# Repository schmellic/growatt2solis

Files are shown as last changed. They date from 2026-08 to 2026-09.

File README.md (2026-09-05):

# Growatt GBLI 6532 → Solis S6-EH1P8K-L-PLUS CAN translator

An ESP32 gateway that sits between a Growatt GBLI 6532 battery and a Solis
S6-EH1P8K-L-PLUS hybrid inverter, decoding Growatt's low-voltage BMS CAN
protocol and re-emitting it as the Pylontech LV CAN protocol the Solis
understands.

> **Status: working, confirmed live (2026-08-31).** This has now run fully
> live - `SNIFF_ONLY` off, a real GBLI6532 talking through a real T-2Can to a
> real Solis S6-EH1P8K-L-PLUS - through a genuine charge cycle and a genuine
> discharge cycle, both with correct current sign, correct SOC, and the
> Solis's own display confirming the datasheet-derived 208.4 A ceiling
> exactly. The four things that used to be inferred rather than confirmed —
> whether the GBLI 6532 emits the `0x311`-series protocol at all, the
> `0x313` voltage scaling, the real `0x301` keepalive payload, and what the
> PCS WAKE pins do — are all settled from real captures, see
> [`captures/`](captures/) and the "Open questions" section of
> [`CLAUDE.md`](CLAUDE.md) for the full evidence trail, including one new
> finding from this live run: the battery protectively disables itself
> (independent of this gateway) if it loses CAN comms, and recovers cleanly.
>
> **Licence: GPLv3.** See [`LICENSE`](LICENSE). You're free to use, modify and
> redistribute this, including commercially — but if you distribute the
> firmware (or a device running it), you must make the corresponding source
> of what you shipped, including your own changes, available under GPLv3 too.

> **Safety.** This sits in the control path of a 48 V, ~100 A battery. A bug here
> can mean the inverter charges past the BMS's limits. The battery's own
> protection MOSFETs remain the last line of defence, but do not treat them as
> the only one. Configure conservative charge voltage / SOC limits in the Solis
> menu as well, commission with the DC breaker in reach, and watch the first
> full charge and discharge cycle before leaving it unattended.

---

## Why a translator is needed

The two devices genuinely do not speak the same language:

| | Growatt GBLI 6532 | Solis S6-EH1P8K-L-PLUS |
|---|---|---|
| Protocol | Growatt LV BMS CAN | Pylontech LV CAN (`PYLON CANBUS V1.2`) |
| Bit rate | 500 kbit/s | 500 kbit/s |
| ID format | 11-bit standard | 11-bit standard |
| **Byte order** | **big-endian** | **little-endian** |
| Frames out | `0x311 0x312 0x313 0x314 0x315–0x318 0x319 0x320 0x321` | `0x351 0x355 0x356 0x359 0x35C 0x35E` |
| Frames in | `0x301` (keepalive from inverter) | `0x305` (keepalive from inverter) |

Bit rate and ID format match, so no rate conversion is needed — but every field
has to be re-laid-out, byte-swapped, and the fault bits re-mapped.

There is **no DIP switch on the GBLI 6532 that makes it emit Pylontech**. Growatt
does protocol selection on the *inverter*, not the battery, so with a Solis on
the other end there is nothing to select. Hence this gateway.

### Frame mapping

| Growatt | → | Pylontech | Notes |
|---|---|---|---|
| `0x311` CVL / CCL / DCL | → | `0x351` | byte-swapped; both current fields stay **positive magnitudes** |
| `0x313` SOC, SOH | → | `0x355` | promoted to uint16 |
| `0x313` V / I / T | → | `0x356` | voltage normalised to 0.01 V; **current sign is the same on both sides (+ = charging)**, so no flip |
| `0x312` protection + warning | → | `0x359` | bit positions differ — explicitly re-mapped |
| `0x319` enables + force-charge | → | `0x35C` | bit positions differ |
| — | → | `0x35E` | fixed `"PYLON "` |
| `0x301` | ← | — | gateway generates it toward the battery |

---

## Hardware

You need **two independent CAN buses**. Do not join them — that is the whole point.

Full shopping list, with prices and the pitfalls, is in **[`PARTS.md`](PARTS.md)**.
Short version:

| Board | `BOARD` in `config.h` | Notes |
|---|---|---|
| **Autosport Labs ESP32-CAN-X2** (~£45) | `BOARD_ESP32_CAN_X2` *(default)* | ESP32-S3. CAN1 = built-in TWAI, CAN2 = MCP2515 @ 16 MHz — exactly this firmware's architecture, nothing to port. Breakable 120 Ω jumpers. Not isolated. |
| **ESP32 DevKit + SN65HVD230 + MCP2515** (~£20) | `BOARD_ESP32_DEVKIT` — use the `translator-devkit`/`sniffer-devkit` PlatformIO envs, no `config.h` edit needed | Budget. **The common blue MCP2515 module is 5 V and the ESP32 is not 5 V tolerant** — see `PARTS.md` before wiring it. |
| **LilyGo T-2Can** (non-FD, ~£27) | `BOARD_LILYGO_T2CAN` — use the `translator-t2can` env, no `config.h` edit needed | ESP32-S3, same TWAI+MCP2515 architecture as the CAN-X2 (just different pins). **Confirmed isolated** — each channel has its own Mornsun TD501MCAN (power + signal isolation, 2500 VDC). Every pin assignment confirmed against a real board, and this is the board this project has actually run live on for days at a time — see `PARTS.md` for the full confirmation trail. |

Pin assignments for all supported boards live in the `BOARD` block at the top of
`config.h`.

### Termination

120 Ω at each end of each bus, and **only** at the ends. Both of your buses are
two-node: ESP32↔battery, and ESP32↔Solis.

- **Inverter bus:** the Solis terminates internally, so the ESP32 side keeps its
  terminator. End to end you should measure ~60 Ω.
- **Battery bus:** the GBLI terminates its end, so again keep the ESP32's. ~60 Ω.
- **When sniffing a live bus, remove the terminator entirely** — see
  [`SNIFFING.md`](SNIFFING.md). A third resistor on an already-terminated bus can
  break the working link.

Measure with a multimeter before powering anything.

---

## Wiring

### Battery end — GBLI 6532 **PCS** port

The GBLI 6532 has three RJ45 sockets. Use **PCS** (the inverter-facing one). Do
**not** use Link-In / Link-Out — those carry the inter-battery bus on different
pins and would silently not work.

| Pin | Signal |
|---|---|
| 1 | RS485-B |
| 2 | RS485-A |
| 3 | GND-ISO |
| **4** | **CAN_H** ← blue |
| **5** | **CAN_L** ← blue/white |
| 6 | GND-ISO |
| 7 | PCS-WAKE− |
| 8 | PCS-WAKE+ |

### Inverter end — Solis battery COM port

| Pin | Signal |
|---|---|
| **4** | **CAN_H** ← blue |
| **5** | **CAN_L** ← blue/white |

T568B on both ends. Pins 4/5 on both sides means a standard patch cable is
pin-compatible — you're just cutting each one and landing it on the ESP32.

### Two things that catch people out

1. **The WAKE pair (PCS pins 7/8) — not actually needed, don't wire it.**
   Earlier revisions of this doc suspected the GBLI needed WAKE driven to
   come out of sleep. Since ruled out three independent ways (validated
   optocoupler monitoring, direct multimeter reading, and a CAN-only cable
   that sustained *and* revived a real pack with WAKE physically absent —
   see `CLAUDE.md`'s open questions) — plain CANH/CANL is all you need. If
   you see nothing on the battery bus, check wiring/termination/TX-RX swap
   first, not WAKE.
2. **The master-select plug.** The GBLI uses plugs on the Link-In/Link-Out ports
   to elect the master pack. A standalone battery still needs the correct plug
   fitted or it may never enumerate.

### Termination

120 Ω at each end of each bus. The Solis has termination built in, so fit one
120 Ω resistor across CAN_H/CAN_L at the ESP32's inverter-side transceiver.
End-to-end you should measure ~60 Ω. Same on the battery side.

---

## Build

PlatformIO:

```bash
pio run -t upload           # ESP32-CAN-X2 (default)
pio device monitor
```

On the budget ESP32 DevKit board, use `-e translator-devkit` (or
`-e sniffer-devkit`) instead — it targets the classic ESP32 and sets
`BOARD_ESP32_DEVKIT` for you, no `config.h` edit required. On a LilyGo T-2Can,
use `-e translator-t2can` (the plain `sniffer` env already targets it for
phase-1 sniffing — see `PARTS.md`).

Arduino IDE: install **coryjfowler/MCP_CAN_lib**, copy `src/*.cpp` and `src/*.h`
into a sketch folder, rename `main.cpp` to match the folder.

Run the host-side tests any time you change the translation logic — they check
byte-level encoding, the endianness flip, flag re-mapping, clamping and the
stale-link derate path, with no hardware required:

```bash
cd test && g++ -std=c++17 -I../src -o test_translate test_translate.cpp && ./test_translate
```

---

## Commissioning — do these in order

### Step 1 — sniff the existing Growatt link *(do this first)*

If the batteries are still connected to a Growatt inverter, tap that live bus
before changing anything. It settles four things that no datasheet does: whether
the GBLI really speaks this protocol, the `0x313` voltage scaling, the real
`0x301` keepalive payload, and what the WAKE pins do.

Full procedure in **[`SNIFFING.md`](SNIFFING.md)**. It uses a separate
listen-only firmware build that cannot disturb the working system:

```bash
pio run -e sniffer-devkit -t upload && pio device monitor
```

If the Growatt is already gone, the same build works against the battery alone —
you just won't capture `0x301`.

### Step 2 — fold what you learned into `config.h`

- Set `GROWATT_0x313_VOLT_SCALE` to `VS_0V01` or `VS_0V1` instead of `VS_AUTO`.
- If the real `0x301` payload differs from the spec example, update
  `sendGrowattKeepalive()` in `src/main.cpp`.
- If `0x312` reported more than one pack, check `PYLON_PACK_COUNT`.

### Step 3 — dry-run the translator on the battery alone

Build the `translator` env with `SNIFF_ONLY` still `true`, battery bus connected,
inverter bus not. Confirm the summary line is sane:

```
[42s] OK V=52.50V I=+20.0A T=23.4C SOC=62% SOH=100% | CVL=56.8V CCL=60.0A DCL=90.0A | ...
```

SOC should match the Growatt app. Current should be positive while charging.

### Step 4 — configure the Solis

Confirmed against the real Solis manual (2026-08-31). Two menu paths get you
there:

- First-time quick setup: `Inverter Time → Meter Setting → Grid Code →
  Storage mode → Battery Model`
- Later, via the detailed menu: Home page → `SYSTEM SETTING` → `Storage Mode`
  (mode/reserve settings) and → `Battery Setting` (the current/SOC limits
  below)

Battery Model: **`PYLON_LV`**.

(`Lithium Battery LV` is the documented fallback and also works, but `PYLON_LV`
is the profile a Solis has been verified against with this protocol.)

On the `Battery Setting` screen:

| Setting | Manual's range/default | Recommended starting value |
|---|---|---|
| Max charge current | settable | **~20–30 A**, not the pack's theoretical max |
| Max discharge current | settable | **~20–30 A**, same reasoning |
| Over discharge | 5–40%, default 20% | manual default is fine |
| Recovery | over-discharge +1–20% | manual default is fine |
| Force charge | must be < Over discharge < Recovery | leave at default |
| Max charge SOC | default 100% | **95%**, not 100% |

**Why start well below the pack's real capability:** this is the first time
the whole chain - BMS → gateway → Solis → actual power flow - runs live. Low
current keeps any real mistake small and slow to develop while you watch the
first cycle. Raise it in steps once you've seen a clean cycle, rather than
jumping straight to the pack's rating. This project's gateway clamps
everything to a per-pack ceiling of 104.2 A - confirmed against the real
GBLI6532 datasheet (5 kW / 104.2 A max) - multiplied by the live pack count
from `0x312` (`CCL_MAX_PER_PACK_dA`/`DCL_MAX_PER_PACK_dA` in `config.h`), so
a 2-pack system's real ceiling is 208.4 A. That's a real confirmed rating,
not a soft guess, but it's still well above where you'd want to start a
first live test.

**Why 95% not 100% for Max charge SOC:** the Solis appears to partly ignore
the CAN charge-voltage limit and use its own float setting, so **do not rely
on `0x351` CVL as your only over-charge protection** - capping SOC at 95%
gives a real margin independent of anything CAN-based.

### Step 5 — go live

Set `SNIFF_ONLY` to `false`, reflash, connect the inverter bus. Within a few
seconds the Solis should stop reporting `Batt_Comm_FAIL` and show the battery
SOC. `inv0x305=yes` in the serial summary confirms the inverter is talking back.

Watch a full charge and a full discharge before leaving it alone. Check that the
inverter's reported battery power direction matches reality — if charge/discharge
appear inverted, the `0x356` current sign needs flipping (it shouldn't; both
protocols use positive = charging, but it's the one thing worth eyeballing).

---

## Failure behaviour

| Condition | Response |
|---|---|
| No battery frames yet | Nothing transmitted; Solis raises `Batt_Comm_FAIL` and stays disconnected |
| Battery silent > 5 s | Charge and discharge current limits forced to 0, `0x35C` enables cleared, `0x359` system-error set |
| Battery silent > 30 s | Transmission stops entirely; Solis faults and disconnects |
| BMS reports a protection | Re-mapped into `0x359`; Solis surfaces it as `Alarm-BMS` |
| Absurd BMS values | Clamped to the ceilings in `config.h` before forwarding |

The design principle throughout: when in doubt, ask the inverter for **less**,
and fail toward disconnection rather than toward uncontrolled current.

---

## A note on Battery-Emulator

[dalathegreat/Battery-Emulator](https://github.com/dalathegreat/Battery-Emulator)
already contains a mature, field-proven `PYLON-LV-CAN` **inverter** implementation —
the exact output side this project needs. What it lacks is a Growatt **low-voltage**
battery decoder (it supports Growatt ARK **HV** only).

So the better long-term route, once you've confirmed the frame layout on your own
pack, is to contribute a `GROWATT-LV-BATTERY` decoder to that project. You'd
inherit its webserver, MQTT/Home Assistant integration, OTA updates, event log and
its much broader testing — and `translate.h` here is essentially the decoder that
would need porting.

Worth knowing if you do: Battery-Emulator's `PYLON-LV-CAN.cpp` `0x359` over-current
logic appears to have a sign bug (it treats positive current as discharge, which
contradicts its own datalayer convention). This project drives those bits from the
BMS's own protection flags instead, which is more reliable anyway.

---

## Protocol references

- Growatt BMS CAN-Bus protocol, low voltage — [V1.04 PDF](https://www.amosplanet.org/wp-content/uploads/2022/04/Growatt-BMS-CAN-Bus-protocol-low-voltage-V1.04-1.pdf)
- PYLON CANBUS protocol V1.2 — [spec PDF](https://akkudoktor.net/uploads/short-url/oLZIl9bFdMC1doN4OnIvXbazHMl.pdf)
- Solis Modbus register map (registers 33141–33146 mirror the BMS CAN frames, which is how the field scalings were cross-checked) — [PDF](https://akkudoktor.net/uploads/short-url/kbwIjN8pl8idrCP04UstaxtSmlC.pdf)
- GBLI 6532 quick installation guide (PCS/Link pinouts) — [PDF](https://solsol.eu/file/view/1805/growatt_instman_gbli-6532-quick-guide_en.pdf)
- Solis S6-EH1P8K-L-PLUS user manual — [PDF](https://139708663.fs1.hubspotusercontent-eu1.net/hubfs/139708663/Fiches%20techniques/Solis/Solis_Manual_S6-EH1P8K-L-PLUS_EUR_V1,2(20251030).pdf)
- `martc55/Jbd2Solis` — a JBD-BMS→Solis Pylon emulator, verified working against a Solis LV hybrid — [GitHub](https://github.com/martc55/Jbd2Solis)
- `edibg/growattArkCAN` — independent capture of Growatt `0x311`/`0x313` — [GitHub](https://github.com/edibg/growattArkCAN)

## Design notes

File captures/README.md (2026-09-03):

# CAN captures

Raw serial output from `pio run -e sniffer`, committed so the protocol decoding
can be checked against real traffic rather than against a datasheet.

**This is the point of the repo.** Growatt's LV BMS CAN protocol is documented,
but I could find no published capture from a **GBLI 6532** specifically — every
byte layout in `src/translate.h` is inferred from the spec plus a capture of the
sibling ARK pack. A capture here turns inference into fact.

## Capturing

```bash
pio run -e sniffer-devkit -t upload   # plain ESP32 DevKit + SN65HVD230 (phase 1 hardware)
pio device monitor | tee captures/$(date +%F)-gbli6532-sph6000.log
```

Let it run for at least a few minutes, ideally spanning a charge→discharge
transition so the signed current field is exercised in both directions.

**Also worth a separate capture: a cold boot.** Start logging *before*
powering the GBLI/inverter link on, not after — a steady-state capture can't
show the `0x301`/`0x311` handshake or when WAKE+ toggles relative to it,
since both only happen once at power-on. See "Bonus: capture a cold boot" in
`SNIFFING.md` for the detailed procedure. The interesting part is the first
~30 seconds; a longer tail afterwards is free insurance but not where the
handshake data is.

## Naming

```
YYYY-MM-DD-<battery>-<inverter>-<what-was-happening>.log
```

e.g. `2026-08-24-gbli6532-sph6000-idle.log`,
`2026-08-24-gbli6532-sph6000-charging-20A.log`,
`2026-08-24-gbli6532-sph6000-coldboot.log`

## What to note alongside each capture

Add a line to the table below. The cross-checks are what make a capture useful —
a log with no reference readings can't resolve a scaling question.

| Capture | Pack V (app/meter) | SOC (app) | Current (app) | Notes |
|---|---|---|---|---|
| _example_ | 52.5 V | 62 % | +20 A charging | |
| `2026-08-23-gbli6532-sph6000-coldboot.log` | not cross-checked | not cross-checked | not cross-checked | Real cold boot into a full idle → discharge (to −9.8 A) → charge (to +7.9 A) cycle, via manually toggling solar off/on. Resolved most of `CLAUDE.md`'s open questions 1, 2, 3, 5, 6. CAN-reported: 53.20–53.40 V, SOC 99%. |
| `2026-08-23-gbli6532-sph6000-battery-only.log` | not cross-checked | not cross-checked | not cross-checked | Battery powered (via its POWER button) with the inverter left off. Shows the battery transmits `0x311` etc. on its own but stays in a disabled `mode=0` state (`CCL=DCL=0.0A`) with no inverter present. CAN-reported: ~53.1 V, SOC 99-100%. |
| `2026-08-23-gbli6532-sph6000-wake-test.log` | not cross-checked | not cross-checked | not cross-checked | Inverter powered first (alone for a while, `0x301` only), then battery POWER button pressed with the exact moment noted live. Shows `mode=0 → mode=1` (fully enabled) within 2-4 seconds of the battery's first frame. Resolved `CLAUDE.md` open question 4 (WAKE not needed). |
| `2026-08-31-gbli6532-t2can-translator-dryrun.log` | not cross-checked | 96% | +0.0A idle | **First-ever capture from the real translator firmware (`translator-t2can`), not the sniffer** - README's commissioning Step 3, battery bus only, inverter bus unconnected. `chg=0 dis=0` on reconnect → `chg=1 dis=1, CCL=DCL=25.6A` within 4s, matching the wake-test pattern exactly. Clean throughout: SOH=99%, packs=2, no faults, `inv0x305=no` correctly reflecting no inverter connected. |
| `2026-08-31-gbli6532-t2can-solis-live-nodc.log` | not cross-checked | 87% | +0.0A idle | First `SNIFF_ONLY` off run against the real Solis, but with DC power deliberately left disconnected - confirms the entire CAN/data path (real Pylon frames, real Solis interpreting them, `inv0x305=yes`) with zero possibility of real current flow. Solis's own display showed `CCL`/`DCL=208.4A` exactly matching the datasheet-derived ceiling, SOC/voltage matching. Solis itself correctly reported "No Battery" as its overall status with DC disconnected - sensible behavior, distinguishing "valid BMS comms" from "usable connected battery". |
| `2026-08-31-gbli6532-t2can-solis-live-charging.log` | not cross-checked | 86-87% | -47.2A to +4.8A | **First fully live run** - `SNIFF_ONLY` off, real Solis attached, DC connected, README Step 5. Confirmed `CCL=DCL=208.4A` on the Solis's own display exactly matching the datasheet-derived 2-pack ceiling. Also captured a real event: the T-2Can was physically disconnected mid-discharge (to move it to a laptop) - battery responded with a protective `chg=0 dis=0` disable and its ALM light/relays opening (t=116s), recovering cleanly within ~4.5 minutes of reconnection (t=390s) with no repeat. `prot=`/`warn=` stayed `0000` throughout the whole event - whatever triggers this protective response isn't visible in the `0x312` bytes this project currently decodes. See `CLAUDE.md`'s safety posture notes. |
| `2026-08-31-gbli6532-t2can-laptop-power-10min.log` | 53.0-53.2V | 84% | -32.4A to +0.0A | Raw serial capture (`cat /dev/ttyACM0`, not `pio device monitor` - that needs a real TTY and can't run backgrounded/unattended) while diagnosing a reported "disconnects after ~10 minutes" issue. Gateway itself was rock solid throughout - `inv0x305=yes` held, no reboot, keepalive never missed a beat - but the battery's own `0x311` enable bits flipped `chg=1 dis=1` → `chg=0 dis=0` at t=648s (10m48s) and stayed disabled for the rest of the 16+ minute capture, no self-recovery. `prot=`/`warn=` stayed `0000`. First two clean measurements of the exact 594 s enable-to-disable interval (t=58s→652s and t=1090s→1684s, identical to the second). See `CLAUDE.md` open question 8 - unresolved. |
| `2026-08-31-gbli6532-sph6000-t2can-sniffer-594s-test.log` | not cross-checked | not cross-checked | +0.0A to -57.1A | Real SPH6000 reconnected directly to the battery (one shared bus, same RJ45-splitter tap technique as the original `SNIFFING.md` procedure), T-2Can as a passive listen-only tap (`sniffer-t2can` env, new - the plain `sniffer` env is missing the `ARDUINO_USB_CDC_ON_BOOT` flag the T-2Can needs). Ran 14m51s with **zero disables** - `chg_en=1 dis_en=1` the whole time, including through a sustained -56.6A real discharge. The decisive test for open question 8: a real Growatt inverter does not hit the 594s wall this gateway does. Also confirmed the real `0x301` payload is byte-for-byte identical to what this gateway sends. |
| `2026-08-31-gbli6532-t2can-batteryonly-594s-clean.log` | ~53.1V | 72% | +0.0A idle | Battery ↔ T-2Can only - no Solis, no SPH6000, cleanest possible topology, running the newly-instrumented `translator-t2can` (`VERBOSE_STATS` added to `main.cpp`/`config.h`). Confirmed the 594s interval a third time, independently: enable at t=68s (after a manual power cycle triggered by a brief comms gap from reflashing), disable at t=664s = 596s, within the 2s print-resolution margin of the first two measurements. Rules out the Solis or SPH6000 having anything to do with the timer - it's purely between this gateway's replay and the battery. |
| `2026-08-31-gbli6532-t2can-twai-health-594s.log` | ~53.0-53.1V | 70-72% | +0.0A idle | Battery ↔ T-2Can only again, this time with TWAI bus-health stats (`tx_err`/`rx_err`/`tx_failed`/`rx_missed`/`rx_overrun`/`arb_lost`/`bus_err`) also logged. Steady-state health was completely clean throughout (all zero except a one-time startup `rx_missed=111` that never grew) right up to and through another clean disable at t=518s (enable t=10s, so 508s - within the usual margin). Rules out an electrical/bus-health difference as the cause, at least in this clean two-node topology. |
| `2026-09-02-gbli6532-sph6000-devkit-txrx-fixed-test.log` | 51.9-53.1V | ~70% | +0.0A idle | Phase-1 DevKit + SN65HVD230, confirming the fix for a real "BMS Com fault" that turned out to be D(TXD)/R(RXD) wired to the wrong GPIOs (not the ground-loop or termination theories tried first, both real fixes in their own right but not the actual cause). Real `0x301`/`0x311`-series traffic flowing cleanly once corrected, fault cleared on the SPH6000's display. |
| `2026-09-03-gbli6532-sph6000-devkit-can-wake-combined-session.log` | 51.9-53.1V | 21-72% | +0.0A to -57A | The big one: 30 min clean baseline with a WAKE-pin optocoupler monitor running for the first time (zero edges logged the entire time), then a deliberate SPH6000 disconnect/reconnect cycle - disable at t=2388.243s, re-enable at t≈2501.27s, again zero WAKE edges through the whole transition. Also the source of the strongest lead yet: a full byte-diff across every ID (not just the decoded ones) around both transitions found `0x323` byte 4 flipping `00→04` at t=2389.027s (0.8s after disable) and back `04→00` at t=2499.197s (2s before re-enable) - the first CAN-visible signal found all project that actually correlates with this state. See `CLAUDE.md` open question 8. |
| `2026-09-03-gbli6532-devkit-t2can-swap-test.log` | 51.9-53.1V | 21% | +0.0A idle | Independent second data point for the `0x323` byte 4 finding, different session/topology (battery + DevKit sniffer + T-2Can, mid swap-without-power-cycle test, contaminated by a severe bus-error problem from removing the SPH6000's terminator - see the txresult-check log below). Byte 4 flipped to `04` at t=502.053s, disable followed at t=507.5s (5.4s later - the opposite order from the combined-session log, so the exact lead/lag relationship isn't consistent yet). |
| `2026-09-03-gbli6532-t2can-own-perspective-check.log` | 51.9V | 21% | +0.0A idle | T-2Can's own serial output during the swap test, checked because the battery never re-enabled after the swap. Confirmed the T-2Can was receiving real `BAT RX` frames from the battery fine (bus connection genuinely good), but its own `chg=0 dis=0` never flipped - led to checking the TWAI health stats next. |
| `2026-09-03-gbli6532-t2can-txresult-check.log` | - | - | - | Added a debug print logging the actual return value of `twai_transmit()` for the keepalive (previously discarded entirely) - confirmed `ESP_OK` every single call, so the keepalive genuinely is being sent. But the TWAI health stats in the same capture showed `bus_err=852260` and a slowly-recovering `tx_err`, pointing at a severe electrical problem (most likely the bus left under-terminated after removing the SPH6000, with nothing confirmed replacing its terminator) rather than a software/logic issue. Termination re-check was still pending when this session paused. |
| `2026-09-03-wake-positive-control-test.log` | - | - | - | First attempt at a positive-control test for the WAKE-pin optocoupler monitor (deliberately applying a known 3.3V test pulse to confirm the detector circuit actually works before trusting a "no signal" result). Invalid - the test source shared a ground/rail with the ESP32 itself, defeating the point of testing the isolated path. Superseded by `-final` below. |
| `2026-09-03-wake-positive-control-final.log` | ~53.0V | ~72% | not cross-checked | The valid positive-control test, after root-causing the circuit's insensitivity to a too-strong combined pull-up (module's own 10kΩ + ESP32's internal ~45kΩ) and an under-driven LED (fixed with an external 1MΩ-only pull-up plus a 5V/~19mA LED drive). Logged real edges (#0-#3) for the first time, proving the detector genuinely works - a prerequisite for trusting the zero-edges result from the real-system tests. |
| `2026-09-03-gbli6532-sph6000-devkit-wake-corrected-30min.log` | 51.9-53.1V | not cross-checked | +0.0A idle | First real-system WAKE monitor run with the corrected (validated) circuit - 36+ minutes against the real SPH6000, zero WAKE edges logged. Combined with the positive-control validation above, this is trustworthy evidence (not just an unvalidated null result) that WAKE carries no signal in normal operation. |
| `2026-09-03-gbli6532-sph6000-can-only-nowake-test.log` | not cross-checked | not cross-checked | not cross-checked | Real SPH6000 connected via a purpose-built CAN-only cable (RJ45 pins 4/5 only, WAKE genuinely physically absent, not just unmonitored). Ran 41+ minutes sustained with no issues - independent confirmation that WAKE isn't required for normal operation, on top of the pin-monitoring result above. |
| `2026-09-03-gbli6532-t2can-revival-test.log` | 53.9-54.0V | 100% | +0.0A idle | First test of whether this gateway itself (not just the real SPH6000) can revive an already-locked battery via reconnection alone. It could not - `chg_en=0 dis_en=0` stayed locked well past the point where the SPH6000's equivalent reconnection had already worked. Later review found this specific log shows **zero individually-timestamped `0x301` frames** anywhere in its visible ~975-1035s window (only a frozen stats-table row with a placeholder payload), which cast doubt on the result until the keepalive-tx-verify test below confirmed transmission really was reliable in equivalent conditions. Turned out to be superseded anyway: the real cause was the wrong `0x301` payload (see `CLAUDE.md` open question 8's resolution), not a transmission problem. |
| `2026-09-03-gbli6532-t2can-clean-burst-test.log` | 53.9-54.0V | 100% | +0.0A to +0.3A | The key clean single-cycle reference session (pre-payload-fix): gateway-only, perfectly metronomic `0x311` throughout with no burst, natural disable at t=565.357s (~594s pattern, still on the buggy payload), `0x323` byte 4 flip at t=564.246s (third independent confirmation of that correlation, 1.1s *before* the disable this time). Then the real SPH6000 was swapped in and revived the battery at t=760.195s - later re-measured in the revival-repeat log as near-instant (~1.5s) once the inverter was actually live, with most of that apparent gap being the inverter's own self-test/boot time, not battery-side delay. Also where the `0x311` burst-timing phenomenon (bursty cadence correlating with unconfirmed/fresh connections, not with the 594s wall) was characterized. |
| `2026-09-03-gbli6532-sph6000-revival-repeat.log` | 53.6-54.2V | 100% | +0.0A to +0.3A | Careful repeat of the SPH6000 revival test for extra confidence. Battery confirmed still locked at t=21s/44.5s, SPH6000 reconnected at t≈44.5s, `chg_en`/`dis_en` flipped back to 1 at t=46.033s - about 1.5s later, sustained and clean through t=59s+. Corrected the earlier "194.8s locked" framing from the clean-burst-test log: that was mostly the SPH6000's own reconnection/self-test process, not the battery being slow - Paul confirmed directly that the relays click immediately every time the SPH6000 goes back in. |
| `2026-09-03-gbli6532-t2can-keepalive-tx-verify.log` | 53.9-54.0V | 100% | +0.0A to +0.3A | Instrumented rerun (`VERBOSE_KEEPALIVE_TX`, still on the buggy payload) to check whether `twai_transmit()` itself was ever silently failing. Found it returns `ESP_ERR_TIMEOUT` when nothing is on the bus to ACK (expected CAN behavior, 30/30 failures confined to the pre-connection window) but was 100% reliable (`ESP_OK`, `bus_err` frozen, `tx_err` recovering to 0) for the entire 598s enable-to-disable cycle and beyond - ruling out transmit reliability as the cause of the natural disable. Also repeated the gateway self-revival attempt on this verified-good-transmit build: still failed to revive, `0x323` byte 4 read `0x04`, closing out the earlier doubt about the `-revival-test.log` result - the revival failure was real, just not (as it turned out) for a transmission reason. |
| `2026-09-03-gbli6532-t2can-post-revival-check.log` | not cross-checked | not cross-checked | not cross-checked | Brief live-status check partway through the keepalive-tx-verify session, low information value on its own. |
| `2026-09-03-gbli6532-t2can-correctpayload-test.log` | 53.4-53.9V | 100% | +0.0A to +0.3A | **The fix confirmation.** After finding `sendGrowattKeepalive()` had been sending the protocol document's example placeholder payload (`11 22 33 44 55 66 77 88`) instead of the real captured value since the project's first commit, corrected it to the real payload and reflashed. Battery enabled normally at t=51s and **stayed enabled 2793+ seconds (46+ minutes) with zero disables**, nearly 5x past the old ~594s wall - resolving `CLAUDE.md` open question 8. Live-monitored by Paul throughout. |

## Open questions these should answer

1. Does the GBLI 6532 emit `0x311`/`0x312`/`0x313` at all, or something else?
2. Is `0x313` bytes 0–1 scaled **0.01 V** (Growatt spec) or **0.1 V**
   (`growattArkCAN` observation)?
3. What is the real `0x301` payload from a Growatt inverter, and does any byte
   change over time — especially during the power-on handshake, not just in
   steady state?
4. What are the actual transmit periods for each ID? Only `0x301`'s ~1 s cadence
   is documented.
5. What voltage/pattern does the inverter apply to the WAKE pins (PCS 7/8),
   and when relative to the `0x301`/`0x311` handshake? See `CLAUDE.md`'s open
   questions for why this one might mean new hardware, not just new config.
6. Does `0x311` byte 6 or byte 7 carry the charge/discharge-enable bits? This
   project's own tests concluded byte 7; a secondhand report elsewhere claims
   byte 6. See `CLAUDE.md`.

See `SNIFFING.md` for the wiring and the safety notes — in particular, remove the
120 Ω terminator from your transceiver module before tapping a live bus.

## Note

Captures are battery telemetry — voltages, currents, SOC. Nothing personally
identifying, so they're safe to publish. Do check before committing anything
you've hand-annotated, though.

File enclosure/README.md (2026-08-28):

# Enclosure

`BMS_Translator_Case.stl` / `BMS_Translator_Lid.stl` — the 3D-printable
enclosure for the LilyGo T-2Can translator board (Phase 2 hardware),
designed against the real board and the real RJ45-to-RJ45 panel-mount
couplers rather than placeholder dimensions.

Designed externally (Fusion 360), not from a parametric source tracked in
this repo — these STLs are the source of truth. There's no `.scad`/`.f3d`
file here to regenerate them from; if the design needs to change, it's
edited at the source and the STLs re-exported and dropped in here.

## Parts referenced

- LilyGo T-2Can (non-FD) — see `PARTS.md`. Confirmed: CAN connections are
  screw terminals, not onboard RJ45 jacks - each RJ45 coupler wires directly
  to its screw terminal block.
- RJ45-to-RJ45 panel-mount coupler, 2-pack (one per CAN bus) —
  [PENGLIN RJ45 8P8C horizontal female adapter](https://www.amazon.co.uk/dp/B0GGBC8JXG)

## History

An earlier parametric OpenSCAD design (`t2can_enclosure.scad`) lived here
first, built from placeholder/unverified board and coupler dimensions before
either part was in hand. Superseded once the real hardware arrived and a
proper design could be done against it - removed rather than kept as a
stale fallback.

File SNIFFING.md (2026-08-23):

# Sniffing your live GBLI 6532 ↔ Growatt SPH6000 link

Having the batteries currently on a Growatt inverter is the single most useful
thing about your situation. A working Growatt pair on the bench answers four
questions that no datasheet does:

1. **Does the GBLI actually speak the documented `0x311`-series protocol?**
   The Growatt LV BMS CAN spec is public, but I could not find a single published
   capture taken from a **GBLI 6532** specifically. Everything in this firmware's
   battery-side decoding is inferred from the spec plus a capture of the ARK
   pack. Your bus settles it.

2. **Is `0x313` scaled 0.01 V or 0.1 V?** Growatt's own document says 0.01 V; the
   `growattArkCAN` project observed 0.1 V. Both fit in an int16 for a 48 V pack.

3. **What is in `0x301`?** This is the keepalive the inverter sends *to* the
   battery, once per second. Growatt's spec gives an example payload
   (`11 22 33 44 55 66 77 88`) and no semantics at all. Your SPH6000 is sending
   the real thing right now. If the GBLI needs it to stay awake and talking, this
   capture is the difference between the gateway working and the battery going
   silent after 30 seconds.

4. **What do the WAKE pins actually do?** You can measure pins 7/8 on a working
   link instead of guessing.

---

## Before you start

The bus you're tapping is keeping a real battery and a real inverter talking. Two
rules:

- **Listen-only.** The sniffer firmware puts the CAN controller in
  `TWAI_MODE_LISTEN_ONLY`. It never sends an ACK bit, never transmits, never
  sends an error frame. Electrically it's a passive stub. Use the `sniffer`
  build, not `SNIFF_ONLY` in the translator build — the latter still has an
  active controller that ACKs.
- **No third terminator.** Remove the 120 Ω resistor from your SN65HVD230 module
  (see `PARTS.md`). Still the recommended practice even though a real capture
  session ran fine with it left in (40 Ω instead of ~60 Ω) - see the
  real-world update in `PARTS.md` for why that's not a reason to skip it.

---

## Wiring the tap

The GBLI's **PCS** port is the one that goes to the SPH6000 — not Link-In or
Link-Out, which carry a different bus on different pins.

```
  GBLI PCS ──────── existing cable ──────── SPH6000 battery port
                         │
                    RJ45 splitter        ← parallel-wired, all 8 pins
                         │
                    ≤ 30 cm stub
                         │
              RJ45 breakout
                    pin 4 (blue)      → SN65HVD230  CAN_H
                    pin 5 (blue/white)→ SN65HVD230  CAN_L
                                        SN65HVD230  3V3 → ESP32 3V3
                                        SN65HVD230  GND → ESP32 GND
                                        SN65HVD230  CTX → ESP32 GPIO 5
                                        SN65HVD230  CRX → ESP32 GPIO 4
```

Don't connect pins 7/8 (WAKE) — you're not the inverter and shouldn't act like
one. Don't connect the RS485 pair either.

Before plugging in: multimeter across the breakout's pins 4 and 5 with the stub
connected but the ESP32 unpowered. You should read the bus's normal ~60 Ω. If you
read ~40 Ω, you've left a terminator on your module.

---

## Running it

```bash
pio run -e sniffer-devkit -t upload   # plain ESP32 DevKit + SN65HVD230 (phase 1 hardware)
pio device monitor
```

(`sniffer` without `-devkit` targets the ESP32-S3 CAN-X2 board instead — use
`-devkit` for the phase 1 sniffer parts in `PARTS.md`.)

Commands (type the letter, then Enter):

| Key | Does |
|---|---|
| `r` | toggle raw frame logging |
| `d` | toggle decoded Growatt lines |
| `s` | print the statistics table now |
| `c` | clear statistics |

A statistics table prints automatically every 15 s.

---

## What you're looking for

### Expected — the good outcome

```
  ID     count   period(ms)  DLC  last payload             changing
  ----------------------------------------------------------------------
  0x301     120    1000 (998-1002)  8   11 22 33 44 55 66 77 88   ........
  0x311     240     500 (498-503)   8   02 38 02 58 03 84 00 62   ....*..*
  0x312     120    1000 (997-1004)  8   00 00 00 00 01 47 57 10   ........
  0x313     240     500 (498-502)   8   14 82 00 C8 00 EA 3E 64   ***** *.
  0x314     120    1000 (996-1003)  8   1A F8 1C 20 00 0C 00 2B   *.*...**
  0x319     120    1000 (999-1001)  8   60 0D 0A 0D 04 03 08 00   .****...
```

The `changing` column marks bytes that have ever changed value — a quick way to
see which fields are live telemetry and which are constants.

### The three things to write down

**1. The `0x313` voltage scaling.** The decode line prints both interpretations:

```
        0x313  Vraw=5250  -> 52.50V if 0.01V  /  525.0V if 0.1V  |  I=+20.0A ...
```

Compare against the pack voltage in the Growatt ShinePhone app. One of the two
will obviously be right. Then set `GROWATT_0x313_VOLT_SCALE` in `config.h` to
`VS_0V01` or `VS_0V1` rather than leaving it on `VS_AUTO`.

**2. The real `0x301` payload.** The sniffer flags this one specially. If your
SPH6000 sends something other than `11 22 33 44 55 66 77 88`, copy the actual
bytes into `sendGrowattKeepalive()` in `src/main.cpp`. Watch it for a minute —
if any byte changes over time (a counter? a checksum? a command?), that matters,
and it's worth capturing a longer log. A forum user trying the same GBLI6532
pairing with a non-Growatt inverter found that replaying a single static
`0x301` payload (`0B 16 21 2C 37 42 4D 58`, ~10 Hz) was **not** enough on its
own to get the BMS to report charge/discharge-enable — so don't stop at one
captured frame; capture several continuous seconds and watch for it changing.

**2b. Which byte of `0x311` actually carries charge/discharge-enable.** This
project's `translate.h` currently reads them from byte 7 (the low byte of the
big-endian pair) — found via this project's own host tests, correcting an
earlier assumption of byte 6. That same forum thread independently claims
byte 6 (bits 4/5/6 = wake/discharge/charge). Check both bytes in your capture
against what the pack is actually doing (charging vs idle vs discharging) to
settle this for real, rather than trusting either secondhand source.

**3. Anything unexpected.** Frames at IDs this firmware doesn't handle, unusual
periods, or `0x312` reporting a pack count other than 1. Save the whole serial
log — `pio device monitor` can tee to a file:

```bash
pio device monitor | tee growatt-capture-$(date +%F).log
```

### If you see nothing at all

In order of likelihood:

1. CAN_H and CAN_L swapped — try the other way round, you can't damage anything.
2. You tapped Link-In/Link-Out instead of PCS.
3. Termination — you left the resistor on your module, or the splitter has a long
   tail.
4. Wiring standard — check your patch lead is T568B and that pin 4 really is the
   solid blue conductor.

If you see nothing and the battery↔inverter link has *also* stopped working,
unplug immediately: that's the third-terminator failure mode.

### If you see completely different CAN IDs

Then the GBLI 6532 isn't speaking the protocol this firmware assumes, and the
whole battery-side decode needs revisiting. Save the log — that's a solvable
problem, just a different one, and the raw capture is everything needed to solve
it.

---

## Bonus: capture a cold boot

A steady-state capture can't answer two of the open questions: the `0x301`/
`0x311` handshake sequence (open question 3 in `CLAUDE.md`), and whether
WAKE+ toggles at a particular point in that sequence (open question 4). Only
a capture that starts *before* power-on can show that.

- **Start logging before power-on, not after.** Flash and start
  `pio device monitor | tee ...` while the GBLI/inverter link is still cold,
  so `t=0` in the log is genuinely before anything happens. Seeing the
  sniffer's own "30 s with no frames" warning while you get things powered
  up is expected, not a fault.
- **The valuable part is the first ~30 seconds**, not a long run. That's
  where you'd see whether WAKE+ appears before or after the first `0x301`,
  whether `0x311`'s status word/enable bits start at 0 and flip after some
  exchange or come up already set, and whether `0x301`'s payload differs in
  its first few frames versus later (a boot-only counter or command). A
  longer tail afterwards is free insurance for periodicity and catching
  anything infrequent (e.g. `0x320`'s mfr/hw/sw info might only ever send
  once) — worth leaving running for several minutes, but that part isn't
  where the interesting data is.
- **Name this capture distinctly** from a steady-state one, e.g.
  `2026-08-21-gbli6532-sph6000-coldboot.log` — see the naming convention in
  `captures/README.md`.
- **One caution, not a blocker:** if the SPH6000 currently powers anything in
  the house, a deliberate restart briefly interrupts that (whether it fails
  over to grid bypass depends on the setup) — plan around it rather than
  trigger it by surprise.
- If you can, note the wall-clock time of the actual power-on moment
  alongside the log — makes it much easier to find "frame 1 of the real
  sequence" versus noise later.

## Bonus: measure the WAKE pins

While you have a working link in front of you, put a meter on PCS pins 7 and 8
(`PCS-WAKE−` and `PCS-WAKE+`) relative to pin 3 or 6 (`GND-ISO`).

Whatever the SPH6000 is doing there, your gateway will probably need to do the
same, and this is the only easy chance to find out. Note whether it's a voltage,
a short, or open circuit.

This one matters more than it might look. A forum user pairing a GBLI6532
with a non-Growatt inverter reports that driving WAKE+ (pin 8) to +5 V
relative to WAKE− (pin 7/GND), through a series resistor, is enough to wake a
real pack and close its relays — their own experimental value (100 Ω), not a
confirmed spec figure. If that's right, **this project's gateway will need to
actively supply that voltage once the GBLI is no longer connected to a real
Growatt inverter** — nothing in `config.h`/`main.cpp` does that today. Get an
exact reading (voltage, and whether it's constant or pulsed) on the real
SPH6000 link if you can; it would settle both this project's Phase 2 hardware
list and directly answer the open question on that forum thread (still
unanswered as of 2026-08-21) — worth posting back if you get a clean reading.

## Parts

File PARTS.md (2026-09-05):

# Parts list

Two phases. **Phase 1 costs about £15 and answers the questions that decide
everything else** — buy it first, sniff your live Growatt link, then commit to
the phase 2 hardware.

Prices are indicative (Aug 2026, UK) and exclude shipping. AliExpress is roughly
half the Amazon UK price on the generic modules but takes 2–3 weeks.

---

## Phase 1 — sniff the live GBLI ↔ SPH6000 link

You only need **one** CAN channel to listen. This is genuinely the important
purchase: it confirms the frame layout, settles the `0x313` voltage-scaling
question, and captures the real `0x301` keepalive that a genuine Growatt inverter
sends — which is undocumented everywhere I could find.

| # | Part | Qty | ~£ | Notes |
|---|---|---|---|---|
| 1 | **ESP32 DevKit V1** (ESP-WROOM-32, 30-pin) | 1 | 4–8 | Any classic ESP32. Not an ESP32-C3 — you want the TWAI peripheral. |
| 2 | **SN65HVD230 CAN transceiver module** (blue "CJMCU-230" / Waveshare) | 1 | 3–5 | 3.3 V native, so it wires straight to the ESP32 with no level shifting. |
| 3 | **RJ45 breakout board with screw terminals** | 1 | 4–8 | Winford `BRK8P8C`, CZH-Labs, or any "RJ45 to screw terminal" board. |
| 4 | **RJ45 splitter / 2-way buss board**, *or* a spare Cat5 patch lead to sacrifice | 1 | 3–6 | See "How to tap" below. |
| 5 | Dupont jumper wires, USB cable | — | 3 | You probably have these. |

**Total: ~£15–30.**

### ⚠️ Remove the 120 Ω resistor from the SN65HVD230 module

Almost every SN65HVD230 breakout has a 120 Ω termination resistor fitted (usually
`R2`, sometimes a jumper). Your battery↔SPH6000 bus is **already correctly
terminated at both ends**. Adding a third resistor drops the bus to 40 Ω, which
is out of spec and the recommendation below is still to remove it.

**Real-world update (2026-08-23):** a genuine GBLI6532↔SPH6000 link was
sniffed for an extended session - cold boot, idle, a full charge→discharge→
charge cycle, multiple wake tests - with a real SN65HVD230 module confirmed
(multimeter-verified) to still have its 120 Ω resistor fitted, i.e. running
at the out-of-spec 40 Ω the whole time. No communication issues observed on
either the sniffer's reception or the live battery↔inverter link itself. So
this is evidently more tolerant in practice than the strict spec suggests,
at least on a short, low-noise stub - but that's one data point on one
installation, not a green light to skip it. Two reasons to still remove it:
it's simply correct practice with no downside, and Phase 2's `translator`
firmware **actively transmits** on this bus rather than just listening,
which is a different electrical loading situation than passive sniffing.

Desolder it, or cut the jumper, before you plug into anything live. Check with a
multimeter across CAN_H/CAN_L on the module alone — you want open circuit, not
120 Ω.

### How to tap without cutting anything

The GBLI's **PCS** port is the one going to the SPH6000. CAN is on pins 4 (CAN_H,
blue) and 5 (CAN_L, blue/white), and CAN is a multidrop bus, so you can simply
hang a short stub off it:

```
  GBLI PCS ──────── existing cable ──────── SPH6000 battery port
                         │
                    RJ45 splitter
                         │
                    (≤ 30 cm)
                         │
              RJ45 breakout → pins 4,5 → SN65HVD230 → ESP32
```

Keep the stub **under 30 cm**. Don't terminate it. Don't connect pins 7/8 (WAKE)
— you're not the inverter and shouldn't pretend to be.

If you'd rather not buy a splitter: cut a spare patch lead, join blue to blue and
blue/white to blue/white through the breakout, and land a tail on the ESP32.

The sniffer firmware runs the CAN controller in **listen-only mode** — it never
ACKs, never transmits, never sends error frames. Your battery and inverter carry
on working while you watch.

---

## Phase 2 — the translator

Now you need **two** independent CAN channels.

**Resolved: WAKE is not needed.** An earlier forum report suggested actively
driving the PCS WAKE+ pin might be required to wake the pack with a
non-Growatt inverter. This project checked that exhaustively and ruled it
out three independent ways: a validated optocoupler edge-monitor logging
zero WAKE activity through a full disable/re-enable cycle, a direct
multimeter reading of ~0 V against a genuine Growatt inverter, and a
CAN-only cable (WAKE pins physically absent, only CANH/CANL wired) that
both sustained the battery indefinitely and revived it from a locked state
using nothing else. No WAKE-related hardware is needed - two plain CANH/CANL
pairs are enough. See `CLAUDE.md`'s open questions for the full trail.

### Recommended: Autosport Labs ESP32-CAN-X2 — ~$55 / ~£45

| Part | Qty | Notes |
|---|---|---|
| [ESP32-CAN-X2](https://www.autosportlabs.com/product/esp32-can-x2-dual-can-bus-automotive-grade-development-board/) | 1 | ESP32-S3, CAN1 = built-in TWAI, CAN2 = MCP2515 @ 16 MHz |
| RJ45 breakout with screw terminals | 2 | one per bus |
| Cat5 patch leads | 2 | to battery PCS, to Solis battery port |
| 5 V USB supply or 12 V | 1 | board takes 6–20 V on the JST header, or USB-C |

**Why this one:** its architecture is exactly what the firmware already targets —
TWAI on GPIO 6/7 for the battery bus, MCP2515 on SPI (CS 10, SCK 12, MISO 13,
MOSI 11, INT 3) for the inverter bus. It's the default `BOARD` setting in
`config.h`; nothing to port. It also has ±14 kV ESD protection on CAN_H/CAN_L and
**breakable jumpers for the onboard 120 Ω terminators**, which matters — see below.

**Caveat:** no galvanic isolation. Fine in practice for a short, fixed
installation, but see the isolated option below.

**Termination on this board:** both channels ship terminated. On the **Solis
side, break the jumper** — the inverter already terminates its end and the
battery... isn't there, so actually you want to think about this per bus:

- **Battery bus** (ESP32 ↔ GBLI PCS): this is now a two-node bus, ESP32 and
  battery. Keep the ESP32's terminator. Should read ~60 Ω end to end.
- **Inverter bus** (ESP32 ↔ Solis): also two nodes. Solis terminates internally,
  so **break the ESP32's jumper on this channel**. Measure: ~120 Ω, not 60 Ω.

Measure both with the DC breaker open before you power anything.

### Budget alternative: ESP32 DevKit + SN65HVD230 + MCP2515 — ~£20

Reuses your phase 1 parts. Build with the `-devkit` PlatformIO envs
(`pio run -e translator-devkit -t upload`) — no need to edit `config.h`, they
pass `BOARD = BOARD_ESP32_DEVKIT` at compile time.

| Part | Qty | ~£ |
|---|---|---|
| ESP32 DevKit V1 (from phase 1) | 1 | — |
| SN65HVD230 module (from phase 1) | 1 | — |
| MCP2515 + TJA1050 CAN module | 1 | 3–5 |

**There is a real risk here.** The ubiquitous blue MCP2515 module is a **5 V**
board. Its `SO` (MISO) line idles at 5 V, and the ESP32's GPIOs are **not 5 V
tolerant**. Wiring it up naively works for a while and then damages the ESP32.

Your options, least to most effort:

1. **Buy a 3.3 V-native module** — some ship with a TJA1051T/3 or SN65HVD230
   instead of the TJA1050. Read the listing photos carefully; the transceiver part
   number is printed on the chip.
2. **Put a divider on SO only** — 3.3 kΩ / 6.8 kΩ from `SO` to the ESP32's MISO
   to ground. Crude but effective; SPI at these speeds tolerates it.
3. **The split-rail mod** — cut the trace between the MCP2515's VCC and the
   TJA1050's VCC, feed the MCP2515 3.3 V and the TJA1050 5 V, plus a divider on
   the TJA1050's RXD output. Well documented, fiddly, and you're doing surgery on
   a board that sits in a battery safety path.

If you're leaving this installed permanently next to a 6.5 kWh battery, spend the
extra £25 on the CAN-X2 and skip all of that.

### If you want isolation

| Option | ~£ | Notes |
|---|---|---|
| [LilyGo T-2Can](https://github.com/Xinyuan-LilyGO/T-2Can) (non-FD, `T-2Can_V1.0`) | ~£27 | ESP32-S3. **Supported** — `BOARD_LILYGO_T2CAN` / `translator-t2can` env. Corrects an earlier note here: per LilyGo's own pin config and example firmware, it's actually **one TWAI channel + one MCP2515** (same architecture as the CAN-X2, different pins), not two MCP2515s — so no TWAI porting was needed, just pin numbers and a reset-pin pulse the CAN-X2 doesn't need. Its TWAI pins happen to match the CAN-X2's, so the existing `sniffer` env works for phase-1 sniffing on it too. **This is the board the project actually runs live on** - isolation and every pin assignment confirmed against a real board (see below), and proven further by days of real operation against a genuine GBLI6532 and Solis. |
| Stark CMR / BECom | £70+ | DIN-rail, isolated, purpose-built for battery↔inverter gateways. Overkill unless you're going the Battery-Emulator route. |

Galvanic isolation is worth having when one bus reaches a 48 V battery and the
other reaches a grid-tied inverter. It isn't strictly necessary, and plenty of
people run unisolated gateways for years — but it's the difference between a
ground fault costing you an ESP32 and costing you an inverter.

**T-2Can, confirmed against a real board (2026-08-24):**
- **Isolation — CONFIRMED true galvanic isolation, one per channel.** Each CAN
  channel has its own Mornsun TD501MCAN module - an isolated CAN transceiver
  that integrates both power isolation (DC-DC) and signal isolation in one
  package, rated 2500 VDC isolation withstand voltage, 5 V supply, up to
  1 Mbps. Not just split ground planes as originally worried - both the
  battery-side and inverter-side buses are genuinely isolated from the
  ESP32/USB side.
- **CAN connections are screw terminals, not onboard RJ45 jacks.** Wire your
  own RJ45 jacks (or the panel-mount couplers in `enclosure/`) directly to
  the screw terminals - no internal patch cable or onboard-jack pinout to
  worry about matching. Keep pin 4 = CAN_H, pin 5 = CAN_L on your own jacks
  to stay consistent with the GBLI PCS port and Solis COM port wiring
  elsewhere in this project (see `README.md`'s wiring tables).
- **Mornsun TD501MCAN pinout — CONFIRMED from the datasheet** (`TDx01MCAN(HG)`
  series, DIP7): pin 1 RXD (output to MCU side), pin 2 TXD (input from MCU
  side), pin 3 GND, pin 4 VCC (5 V), pin 5 CANG (isolated-side ground), pin 6
  CANL, pin 7 CANH. **Correcting an earlier note here:** CANG does *not* need
  wiring to the remote device - the datasheet's own typical application
  circuit (Fig 1) shows it as NC. It only appears in the optional
  surge-protection circuit (Fig 3), tied to *local* earth through a filter
  resistor/cap, not to the remote device's ground. Standard 2-wire CANH/CANL
  is correct for both buses.
- **There's an MS4553S 3.3V↔5V level shifter between the ESP32 and each
  TD501MCAN** (one per channel, UY1 for CAN-B, UY2 for CAN-A) - not a direct
  wire. Confirmed by tracing the real schematic: ESP32 GPIO 6/7 land on the
  shifter's low-voltage (A) side, the TD501MCAN's RXD/TXD land on its
  high-voltage (B) side. This is why net labels look inconsistent either
  side of it (`TXB_CAN` at the ESP32 vs `CANB_TXD` at the transceiver) -
  they're genuinely different nets bridged by the shifter, not a documentation
  error.
- **GPIO 6/7 direction — CONFIRMED correct, not swapped.** Traced the full
  chain through the level shifter: GPIO 6 → `TXB_CAN` → shifter → `CANB_TXD`
  → TD501MCAN pin 1 (RXD) - so GPIO 6 is correctly the ESP32's TWAI **receive**
  pin. GPIO 7 → `RXB_CAN` → shifter → `CANB_RXD` → TD501MCAN pin 2 (TXD) - so
  GPIO 7 is correctly the ESP32's TWAI **transmit** pin. Matches what
  `config.h` already had (`TWAI_TX_PIN = GPIO_NUM_7`, `TWAI_RX_PIN =
  GPIO_NUM_6`) - the confusing net-name mismatch above made this look like a
  possible swap, but it wasn't one.
- **Which screw terminal block is which — CONFIRMED, including on the
  physical silkscreen.** The MCP2515's `TXCAN`/`RXCAN` pins sit on nets
  `TXA_CAN`/`RXA_CAN` in the schematic, so the MCP2515 drives **CAN-A**; the
  ESP32's direct TWAI connection is **CAN-B**. This project wires CAN-B to
  the **battery** and CAN-A to the **inverter** - matching the existing
  convention - and this is exactly how the real board has been wired for
  its entire live run, so the silkscreen labelling is correct as assumed.
- **MCP2515 oscillator — CONFIRMED 16 MHz** from the schematic (crystal X1,
  marked "16MHZ±10ppm") and independently from the physical crystal's own
  marking ("YC16.0") - not the 8 MHz this project assumed before. `config.h`
  is now pinned to `MCP_16MHZ`.
- **Confirmed non-FD `T-2Can_V1.0`** - the MCP2515 chip is physically visible
  on the board, matching what this project targets (the `T-2Can-Fd` variant
  uses an MCP2518 and a different library instead - not supported here).

No caveats left unconfirmed against the real board as of 2026-08-31. Since
then this exact board has run live against a real GBLI6532 and Solis for
days at a time with correct current flow in both directions, which is
about as strong a confirmation of every pin assignment above as exists.

---

## Consumables

| Item | Notes |
|---|---|
| 120 Ω resistors | a couple spare, for measuring and for fixing termination mistakes |
| Multimeter | non-negotiable — you'll be checking bus resistance and pin continuity |
| Cat5/Cat5e patch leads | 2–3, T568B |
| Small enclosure + DIN clip | for the permanent install |

---

## What to buy right now

Just phase 1. Everything about phase 2 — including whether the mapping in this
firmware is even correct for your pack — depends on what the sniffer shows you.

An ESP32 DevKit, an SN65HVD230 module, an RJ45 breakout, and a splitter. Under
£20, and you'll know within an evening of it arriving whether this whole approach
works.

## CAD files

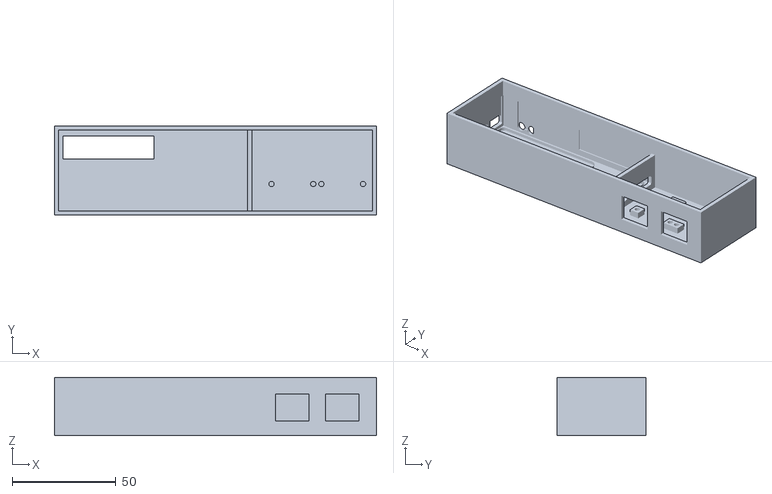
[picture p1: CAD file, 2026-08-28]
enclosure/BMS_Translator_Case.stl
155.0 x 43.0 x 28.0

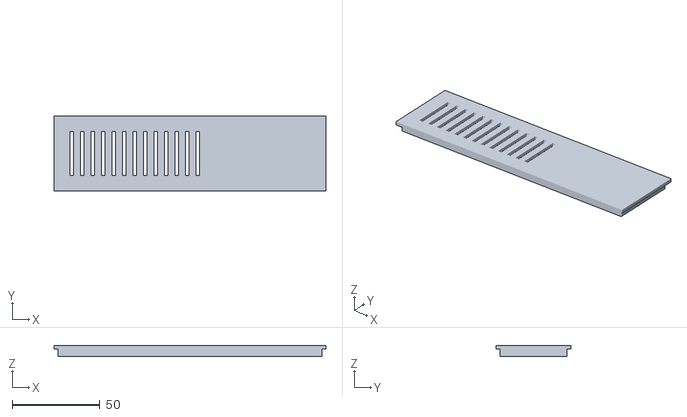
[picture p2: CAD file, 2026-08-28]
enclosure/BMS_Translator_Lid.stl
155.0 x 43.0 x 6.00

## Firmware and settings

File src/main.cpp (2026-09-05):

// SPDX-License-Identifier: GPL-3.0-or-later
// Copyright (C) 2026 Paul <schmellic@gmail.com>
// =============================================================================
//  Growatt GBLI 6532  ->  Solis S6-EH1P8K-L-PLUS   CAN protocol translator
//  -------------------------------------------------------------------------
//  Battery side : Growatt low-voltage BMS CAN protocol
//                 500 kbit/s, 11-bit IDs, BIG-endian
//                 BMS->inv  0x311 0x312 0x313 0x314 0x315-0x318 0x319 0x320
//                 inv->BMS  0x301 (keepalive)
//
//  Inverter side: Pylontech low-voltage CAN (PYLON CANBUS V1.2)
//                 500 kbit/s, 11-bit IDs, LITTLE-endian
//                 BMS->inv  0x351 0x355 0x356 0x359 0x35C 0x35E  @ 1 Hz
//                 inv->BMS  0x305 (keepalive; liveness only)
//
//  Set the Solis battery profile to PYLON_LV.
//
//  Hardware: ESP32 + built-in TWAI (battery bus) + MCP2515 on VSPI (inverter)
//  Library : coryjfowler/MCP_CAN_lib
// =============================================================================

#include <Arduino.h>
#include <SPI.h>
#include <mcp_can.h>
#include "driver/twai.h"
#include "config.h"
#include "translate.h"

static BatteryState batt;
static uint32_t lastInverterAliveMs = 0;
static bool     invSeen = false;

#if VERBOSE_STATS
// -----------------------------------------------------------------------------
//  Per-ID frame rate table, identical format to sniffer.cpp's, added to
//  directly compare real battery-side traffic rates while this gateway is
//  driving the bus against the same table captured while a real Growatt
//  inverter drives it - see CLAUDE.md open question 8. Pure observation,
//  no effect on translation/safety behavior.
// -----------------------------------------------------------------------------
#define STATS_MAX_IDS       40
#define STATS_INTERVAL_MS   15000

struct IdStat {
    uint32_t id;
    uint32_t count;
    uint32_t firstMs;
    uint32_t lastMs;
    uint32_t minGap;
    uint32_t maxGap;
    bool     used;
};
static IdStat statsTable[STATS_MAX_IDS];
static uint32_t statsTotalFrames = 0;

static void statsRecord(uint32_t id, uint32_t now) {
    IdStat *s = nullptr;
    for (int i = 0; i < STATS_MAX_IDS; i++)
        if (statsTable[i].used && statsTable[i].id == id) { s = &statsTable[i]; break; }
    if (!s) {
        for (int i = 0; i < STATS_MAX_IDS; i++)
            if (!statsTable[i].used) {
                s = &statsTable[i];
                s->used = true;
                s->id = id;
                s->minGap = 0xFFFFFFFF;
                break;
            }
    }
    if (!s) return;
    if (s->count == 0) {
        s->firstMs = now;
    } else {
        uint32_t gap = now - s->lastMs;
        if (gap < s->minGap) s->minGap = gap;
        if (gap > s->maxGap) s->maxGap = gap;
    }
    s->lastMs = now;
    s->count++;
    statsTotalFrames++;
}

// -----------------------------------------------------------------------------
//  TWAI bus-health stats: error counters and controller state, not visible at
//  the decoded-frame level at all. Added after frame content, timing and rate
//  were all checked and ruled out as differences from a real Growatt inverter
//  - see CLAUDE.md open question 8. If this gateway's transceiver is doing
//  something subtly different electrically, this is where it would show up.
// -----------------------------------------------------------------------------
static const char *twaiStateName(twai_state_t s) {
    switch (s) {
    case TWAI_STATE_STOPPED:    return "STOPPED";
    case TWAI_STATE_RUNNING:    return "RUNNING";
    case TWAI_STATE_BUS_OFF:    return "BUS_OFF";
    case TWAI_STATE_RECOVERING: return "RECOVERING";
    default:                    return "?";
    }
}

static void twaiHealthPrint() {
    twai_status_info_t s;
    if (twai_get_status_info(&s) != ESP_OK) {
        Serial.println(F("  [twai_get_status_info failed]"));
        return;
    }
    Serial.printf(
        "  TWAI: state=%s  tx_err=%lu rx_err=%lu  tx_failed=%lu  "
        "rx_missed=%lu rx_overrun=%lu  arb_lost=%lu  bus_err=%lu\n",
        twaiStateName(s.state),
        (unsigned long)s.tx_error_counter, (unsigned long)s.rx_error_counter,
        (unsigned long)s.tx_failed_count,
        (unsigned long)s.rx_missed_count, (unsigned long)s.rx_overrun_count,
        (unsigned long)s.arb_lost_count, (unsigned long)s.bus_error_count);
}

static void statsPrint() {
    Serial.println();
    Serial.println(F("---- battery-bus rate stats (VERBOSE_STATS) ----------------------------"));
    Serial.printf ("  %lu frames, %lu s elapsed\n",
                   (unsigned long)statsTotalFrames, (unsigned long)(millis() / 1000));
    Serial.println(F("  ID     count   period(ms)  (min-max gap)"));
    for (int i = 0; i < STATS_MAX_IDS; i++) {
        if (!statsTable[i].used) continue;
        IdStat &s = statsTable[i];
        uint32_t mean = (s.count > 1) ? (s.lastMs - s.firstMs) / (s.count - 1) : 0;
        Serial.printf("  0x%03X  %6lu  %5lu (%lu-%lu)\n",
                      (unsigned)s.id, (unsigned long)s.count, (unsigned long)mean,
                      (unsigned long)(s.minGap == 0xFFFFFFFF ? 0 : s.minGap),
                      (unsigned long)s.maxGap);
    }
    Serial.println(F("--------------------------------------------------------------------------"));
    Serial.println();
}
#endif

MCP_CAN MCP(MCP_CS_PIN);

// -----------------------------------------------------------------------------
static void blink(uint8_t times) {
#if STATUS_LED_PIN >= 0
    for (uint8_t i = 0; i < times; i++) {
        digitalWrite(STATUS_LED_PIN, HIGH); delay(60);
        digitalWrite(STATUS_LED_PIN, LOW);  delay(120);
    }
#else
    (void)times;
#endif
}

static void dumpFrame(const char *tag, uint32_t id, uint8_t len, const uint8_t *d) {
    char line[96];
    int n = snprintf(line, sizeof(line), "%s 0x%03X [%u] ", tag, (unsigned)id, (unsigned)len);
    for (uint8_t i = 0; i < len && n < (int)sizeof(line) - 4; i++)
        n += snprintf(line + n, sizeof(line) - n, "%02X ", d[i]);
    Serial.println(line);
}

// =============================================================================
//  Battery bus  (ESP32 TWAI)
// =============================================================================
static bool twaiInit() {
    twai_general_config_t g = TWAI_GENERAL_CONFIG_DEFAULT(TWAI_TX_PIN, TWAI_RX_PIN, TWAI_MODE_NORMAL);
    g.rx_queue_len = 32;
    g.tx_queue_len = 16;
    twai_timing_config_t t = TWAI_TIMING_CONFIG_500KBITS();
    twai_filter_config_t f = TWAI_FILTER_CONFIG_ACCEPT_ALL();
    if (twai_driver_install(&g, &t, &f) != ESP_OK) return false;
    return twai_start() == ESP_OK;
}

static void pollBatteryBus() {
    twai_message_t msg;
    while (twai_receive(&msg, 0) == ESP_OK) {
        if (msg.extd || msg.rtr) continue;      // Growatt LV is 11-bit data only
#if SNIFF_ONLY
        dumpFrame("BAT RX", msg.identifier, msg.data_length_code, msg.data);
#endif
#if VERBOSE_STATS
        statsRecord(msg.identifier, millis());
#endif
        decodeGrowatt(batt, msg.identifier, msg.data_length_code, msg.data, millis());
    }
}

static void sendGrowattKeepalive() {
#if GROWATT_0x301_ENABLE
    twai_message_t m;
    memset(&m, 0, sizeof(m));
    m.identifier = GW_KEEPALIVE;
    m.data_length_code = 8;
    // Real payload captured from a genuine Growatt SPH6000, static across
    // idle/discharge/charge/boot - see CLAUDE.md open question 3. This was
    // WRONGLY the protocol doc's example placeholder (0x11..0x88) from the
    // very first commit until 2026-09-03 - every prior gateway session in
    // this project sent that placeholder, never this real value.
    static const uint8_t p[8] = {0x0B, 0x16, 0x21, 0x2C, 0x37, 0x42, 0x4D, 0x58};
    memcpy(m.data, p, 8);
#if VERBOSE_KEEPALIVE_TX
    esp_err_t r = twai_transmit(&m, pdMS_TO_TICKS(10));
    Serial.printf("[keepalive] twai_transmit() -> %s\n", esp_err_to_name(r));
#else
    twai_transmit(&m, pdMS_TO_TICKS(10));
#endif
#endif
}

// =============================================================================
//  Inverter bus  (MCP2515)
// =============================================================================
static bool mcpInit() {
#ifdef MCP_RST_PIN
    // Some boards (e.g. LilyGo T-2Can) break out MCP2515 RST as a GPIO
    // instead of tying it on-board; it needs an active-low pulse to bring
    // the chip out of reset before SPI will get a response.
    pinMode(MCP_RST_PIN, OUTPUT);
    digitalWrite(MCP_RST_PIN, HIGH);
    delay(100);
    digitalWrite(MCP_RST_PIN, LOW);
    delay(100);
    digitalWrite(MCP_RST_PIN, HIGH);
    delay(100);
#endif
    SPI.begin(MCP_SCK_PIN, MCP_MISO_PIN, MCP_MOSI_PIN, MCP_CS_PIN);
    if (MCP.begin(MCP_ANY, CAN_500KBPS, MCP_CRYSTAL) != CAN_OK) return false;
    MCP.setMode(MCP_NORMAL);
    pinMode(MCP_INT_PIN, INPUT);
    return true;
}

static void pollInverterBus() {
    while (MCP.checkReceive() == CAN_MSGAVAIL) {
        unsigned long rxId = 0; uint8_t len = 0; uint8_t buf[8];
        MCP.readMsgBuf(&rxId, &len, buf);
        uint32_t id = (uint32_t)(rxId & 0x1FFFFFFFUL);
        if (id == PY_305) { lastInverterAliveMs = millis(); invSeen = true; }
#if SNIFF_ONLY
        dumpFrame("INV RX", id, len, buf);
#endif
    }
}

static void sendPylonBurst(bool derate) {
    PylonBurst burst = buildPylon(batt, derate);
    for (int i = 0; i < 6; i++) {
        MCP.sendMsgBuf(burst.f[i].id, 0, burst.f[i].len, burst.f[i].data);
#if VERBOSE_TX
        dumpFrame("INV TX", burst.f[i].id, burst.f[i].len, burst.f[i].data);
#endif
        if (i < 5) delay(PYLON_TX_GAP_MS);
    }
}

// =============================================================================
static void printSummary(bool derate, bool silent) {
    char line[240];
    snprintf(line, sizeof(line),
        "[%lus] %s%s V=%.2fV I=%+.1fA T=%.1fC SOC=%u%% SOH=%u%% | "
        "CVL=%.1fV CCL=%.1fA DCL=%.1fA | chg=%d dis=%d fc1=%d fc2=%d | "
        "prot=%02X%02X warn=%02X%02X | packs=%u | inv0x305=%s",
        (unsigned long)(millis() / 1000),
        silent ? "SILENT " : (derate ? "DERATE " : ""),
        (batt.have_311 && batt.have_313) ? "OK" : "WAIT",
        batt.pack_v_cV / 100.0f,
        batt.current_dA / 10.0f,
        batt.temp_dC / 10.0f,
        (unsigned)batt.soc_pct, (unsigned)batt.soh_pct,
        batt.cvl_dV / 10.0f, batt.ccl_dA / 10.0f, batt.dcl_dA / 10.0f,
        (int)batt.charge_en, (int)batt.discharge_en,
        (int)batt.force_chg_1, (int)batt.force_chg_2,
        batt.prot1, batt.prot2, batt.warn1, batt.warn2,
        (unsigned)batt.pack_count,
        invSeen ? "yes" : "no");
    Serial.println(line);
}

// =============================================================================
void setup() {
    Serial.begin(115200);
    delay(300);
    Serial.println();
    Serial.println(F("=== Growatt GBLI 6532 -> Solis PYLON_LV translator ==="));
#if SNIFF_ONLY
    Serial.println(F("MODE: SNIFF ONLY - nothing is sent to the inverter."));
#else
    Serial.println(F("MODE: ACTIVE - translating to the inverter."));
#endif

#if STATUS_LED_PIN >= 0
    pinMode(STATUS_LED_PIN, OUTPUT);
    digitalWrite(STATUS_LED_PIN, LOW);
#endif

    if (!twaiInit()) {
        Serial.println(F("FATAL: TWAI (battery bus) init failed."));
        for (;;) { blink(2); delay(800); }
    }
    Serial.println(F("Battery bus (TWAI) up at 500 kbit/s."));

    if (!mcpInit()) {
        Serial.println(F("FATAL: MCP2515 init failed - check CS pin, wiring and crystal (8 vs 16 MHz)."));
        for (;;) { blink(3); delay(800); }
    }
    Serial.println(F("Inverter bus (MCP2515) up at 500 kbit/s."));
    blink(1);
}

void loop() {
    static uint32_t lastPylonTx = 0, lastKeepalive = 0, lastPrint = 0;
#if VERBOSE_STATS
    static uint32_t lastStats = 0;
#endif

    pollBatteryBus();
    pollInverterBus();

    const uint32_t now = millis();

    if (now - lastKeepalive >= GROWATT_0x301_INTERVAL) {
        lastKeepalive = now;
        sendGrowattKeepalive();
    }

    const uint32_t age = (batt.last_rx_ms == 0) ? now : (now - batt.last_rx_ms);
    const bool derate = (batt.last_rx_ms == 0) || (age > BATT_STALE_DERATE_MS);
    const bool silent = (batt.last_rx_ms == 0) || (age > BATT_STALE_SILENCE_MS);

    if (now - lastPylonTx >= PYLON_TX_INTERVAL_MS) {
        lastPylonTx = now;
#if !SNIFF_ONLY
        if (!silent) sendPylonBurst(derate);
#endif
#if STATUS_LED_PIN >= 0
        digitalWrite(STATUS_LED_PIN, (!silent && !derate) ? HIGH : LOW);
#endif
    }

#if VERBOSE_DECODE
    if (now - lastPrint >= 2000) {
        lastPrint = now;
        printSummary(derate, silent);
    }
#endif

#if VERBOSE_STATS
    if (now - lastStats >= STATS_INTERVAL_MS) {
        lastStats = now;
        statsPrint();
        twaiHealthPrint();
    }
#endif
}

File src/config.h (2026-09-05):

// SPDX-License-Identifier: GPL-3.0-or-later
// Copyright (C) 2026 Paul <schmellic@gmail.com>
// =============================================================================
//  config.h  -  Growatt GBLI 6532  ->  Solis S6-EH1P8K-L-PLUS  CAN translator
//  Everything you are likely to want to change lives in this file.
// =============================================================================
#pragma once
#ifdef ARDUINO
#include <Arduino.h>
#endif

// -----------------------------------------------------------------------------
// 0. BOARD
// -----------------------------------------------------------------------------
//  BOARD_ESP32_CAN_X2  : Autosport Labs ESP32-CAN-X2 (ESP32-S3)
//                       CAN1 = built-in TWAI, CAN2 = MCP2515 @ 16 MHz.
//                       Matches this firmware's architecture exactly.
//  BOARD_ESP32_DEVKIT  : plain ESP32 DevKit + SN65HVD230 (TWAI)
//                       + MCP2515 module (see README for the 3.3 V caveat).
//  BOARD_LILYGO_T2CAN  : LilyGo T-2Can (ESP32-S3), non-FD (MCP2515) variant.
//                       Same TWAI+MCP2515 architecture as ESP32-CAN-X2, just
//                       different pins, and its MCP2515 RST line needs an
//                       active-low pulse at boot (see main.cpp). Pins are
//                       LilyGo's own, from github.com/Xinyuan-LilyGO/T-2Can.
//                       CONFIRMED against the real schematic (2026-08-31):
//                       GPIO 7/6 (TWAI) is CAN-B, the MCP2515 drives CAN-A,
//                       and both signals pass through an MS4553S 3.3V<->5V
//                       level shifter per channel before reaching each
//                       channel's isolated Mornsun TD501MCAN transceiver.
#define BOARD_ESP32_CAN_X2   1
#define BOARD_ESP32_DEVKIT   2
#define BOARD_LILYGO_T2CAN   3

// Overridable from platformio.ini via `-D BOARD=...` (see the `*-devkit`
// envs) so switching boards doesn't require editing this file.
#ifndef BOARD
#define BOARD                BOARD_ESP32_CAN_X2
#endif

// -----------------------------------------------------------------------------
// 1. MODE
// -----------------------------------------------------------------------------
// SNIFF_ONLY: do NOT transmit anything to the inverter. Just listen on the
// battery bus and dump every frame to serial. Set to false once verified.
// (For tapping a LIVE battery<->Growatt link, flash the separate `sniffer`
// environment instead - it runs the CAN controller in listen-only mode.)
#define SNIFF_ONLY              false

#define VERBOSE_DECODE          true    // one-line decoded battery summary
#define VERBOSE_TX              false   // dump every outgoing Pylon frame
#define VERBOSE_STATS           true    // periodic per-ID frame rate table (diagnostic,
                                         // same format as sniffer.cpp - added to compare
                                         // real battery-side traffic rates against a real
                                         // Growatt inverter, see CLAUDE.md open question 8
#define VERBOSE_KEEPALIVE_TX    true    // log twai_transmit()'s actual return value for the
                                         // 0x301 keepalive, instead of discarding it - added
                                         // 2026-09-03 while chasing open question 8, still
                                         // actively in use

// -----------------------------------------------------------------------------
// 2. HARDWARE PINS
// -----------------------------------------------------------------------------
#if BOARD == BOARD_ESP32_CAN_X2
    // --- CAN1 (built-in TWAI) -> BATTERY bus
    #define TWAI_TX_PIN         GPIO_NUM_7
    #define TWAI_RX_PIN         GPIO_NUM_6
    // --- CAN2 (MCP2515 over SPI) -> INVERTER bus
    #define MCP_CS_PIN          10
    #define MCP_INT_PIN         3
    #define MCP_SCK_PIN         12
    #define MCP_MISO_PIN        13
    #define MCP_MOSI_PIN        11
    #define MCP_CRYSTAL         MCP_16MHZ
    #define STATUS_LED_PIN      -1      // no convenient user LED; set if you add one

#elif BOARD == BOARD_ESP32_DEVKIT
    // --- Built-in TWAI + SN65HVD230 breakout -> BATTERY bus
    #define TWAI_TX_PIN         GPIO_NUM_5
    #define TWAI_RX_PIN         GPIO_NUM_4
    // --- MCP2515 module on VSPI -> INVERTER bus
    #define MCP_CS_PIN          15
    #define MCP_INT_PIN         27
    #define MCP_SCK_PIN         18
    #define MCP_MISO_PIN        19
    #define MCP_MOSI_PIN        23
    // Blue "niren" MCP2515 boards are usually 8 MHz, black ones often 16 MHz.
    // The wrong value here means no communication at all.
    #define MCP_CRYSTAL         MCP_8MHZ
    #define STATUS_LED_PIN      2
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

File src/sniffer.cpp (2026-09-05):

// SPDX-License-Identifier: GPL-3.0-or-later
// Copyright (C) 2026 Paul <schmellic@gmail.com>
// =============================================================================
//  sniffer.cpp  -  LISTEN-ONLY CAN sniffer for the Growatt battery bus
//  -------------------------------------------------------------------------
//  Purpose: tap the LIVE link between the GBLI 6532 and a Growatt SPH6000 and
//  record exactly what both ends say, WITHOUT disturbing the working system.
//
//  The TWAI controller runs in TWAI_MODE_LISTEN_ONLY: it never sends an ACK
//  bit, never sends an error frame, and never transmits. Electrically the node
//  is a passive stub. This is the only safe way to instrument a bus that is
//  currently keeping a real battery and inverter talking.
//
//  Build:  pio run -e sniffer -t upload && pio device monitor
//
//  Serial commands (type the letter + Enter):
//    r  toggle raw frame logging
//    s  print the statistics table now
//    c  clear all statistics
//    d  toggle Growatt decode lines
// =============================================================================

#include <Arduino.h>
#include "driver/twai.h"
#include "config.h"
#include "translate.h"

#define MAX_IDS         40
#define STATS_INTERVAL  15000

struct IdStat {
    uint32_t id;
    uint32_t count;
    uint32_t firstMs;
    uint32_t lastMs;
    uint32_t minGap;
    uint32_t maxGap;
    uint8_t  dlc;
    uint8_t  last[8];
    uint8_t  changed;      // bitmask: which byte positions have ever changed
    bool     used;
};

static IdStat stats[MAX_IDS];
static uint32_t totalFrames = 0;
static bool logRaw    = true;
static bool logDecode = true;

static BatteryState batt;

// =============================================================================
//  WAKE pin monitor - DevKit diagnostic build only.
//  GPIO16 - PCS-WAKE+ tapped through a PC817 optocoupler (active-low output:
//  HIGH = WAKE+ absent/idle, LOW = WAKE+ energized). Added 2026-09-01 to test
//  whether a real Growatt inverter pulses WAKE rather than holding it at a
//  sustained level - a multimeter's steady-state reading can't catch a brief
//  pulse, this can. See CLAUDE.md open question 8. Not part of this board's
//  normal pin set - only meaningful with the optocoupler circuit wired up.
// =============================================================================
#if BOARD == BOARD_ESP32_DEVKIT
#define WAKE_MONITOR_PIN 16
#define WAKE_LOG_SIZE    128

struct WakeEvent { uint32_t ms; uint8_t level; };
static volatile WakeEvent wakeLog[WAKE_LOG_SIZE];
static volatile uint16_t  wakeHead = 0;
static uint16_t           wakePrinted = 0;
static volatile uint32_t  wakeEdgeCount = 0;

void IRAM_ATTR wakeISR() {
    uint16_t h = wakeHead;
    wakeLog[h].ms = millis();
    wakeLog[h].level = (uint8_t)digitalRead(WAKE_MONITOR_PIN);
    wakeHead = (uint16_t)((h + 1) % WAKE_LOG_SIZE);
    wakeEdgeCount++;
}

static void wakeMonitorSetup() {
    // Plain INPUT, not INPUT_PULLUP: the optocoupler's own onboard pull-up
    // turned out far too weak to register the real signal (measured
    // 2026-09-03 - a 1M ohm external pull-up was needed to get a usable
    // swing). The ESP32's internal pull-up (~45k ohm) would sit in
    // parallel with that external resistor and drag the effective value
    // straight back down, undoing the fix - so this pin must rely
    // entirely on the external 1M ohm resistor now, no internal pull.
    pinMode(WAKE_MONITOR_PIN, INPUT);
    attachInterrupt(digitalPinToInterrupt(WAKE_MONITOR_PIN), wakeISR, CHANGE);
    Serial.printf("WAKE monitor armed on GPIO%d (active-low: LOW = WAKE+ energized)\n",
                  WAKE_MONITOR_PIN);
    Serial.printf("Idle level right now: %s\n",
                  digitalRead(WAKE_MONITOR_PIN) ? "HIGH (absent)" : "LOW (energized)");
}

static void wakeMonitorPoll() {
    while (wakePrinted != wakeHead) {
        uint32_t ms    = wakeLog[wakePrinted].ms;
        uint8_t  level = wakeLog[wakePrinted].level;
        Serial.printf("[%lu.%03lus] WAKE edge #%lu -> %s\n",
                      (unsigned long)(ms / 1000), (unsigned long)(ms % 1000),
                      (unsigned long)wakePrinted,
                      level ? "HIGH (idle/absent)" : "LOW (energized)");
        wakePrinted = (uint16_t)((wakePrinted + 1) % WAKE_LOG_SIZE);
    }
}
#endif

// -----------------------------------------------------------------------------
static IdStat *findOrAdd(uint32_t id) {
    for (int i = 0; i < MAX_IDS; i++)
        if (stats[i].used && stats[i].id == id) return &stats[i];
    for (int i = 0; i < MAX_IDS; i++)
        if (!stats[i].used) {
            stats[i].used = true;
            stats[i].id = id;
            stats[i].minGap = 0xFFFFFFFF;
            return &stats[i];
        }
    return nullptr;
}

static void record(uint32_t id, uint8_t dlc, const uint8_t *d, uint32_t now) {
    IdStat *s = findOrAdd(id);
    if (!s) return;
    if (s->count == 0) {
        s->firstMs = now;
    } else {
        uint32_t gap = now - s->lastMs;
        if (gap < s->minGap) s->minGap = gap;
        if (gap > s->maxGap) s->maxGap = gap;
        for (uint8_t i = 0; i < dlc && i < 8; i++)
            if (s->last[i] != d[i]) s->changed |= (uint8_t)(1u << i);
    }
    s->lastMs = now;
    s->dlc = dlc;
    memcpy(s->last, d, dlc > 8 ? 8 : dlc);
    s->count++;
    totalFrames++;
}

// -----------------------------------------------------------------------------
static void printRaw(uint32_t now, uint32_t id, uint8_t dlc, const uint8_t *d) {
    char line[110];
    int n = snprintf(line, sizeof(line), "%8lu.%03lu  0x%03X  [%u]  ",
                     (unsigned long)(now / 1000), (unsigned long)(now % 1000),
                     (unsigned)id, (unsigned)dlc);
    for (uint8_t i = 0; i < dlc && n < (int)sizeof(line) - 4; i++)
        n += snprintf(line + n, sizeof(line) - n, "%02X ", d[i]);
    Serial.println(line);
}
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

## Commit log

2026-08-20 Growatt GBLI 6532 to Solis PYLON_LV CAN translator
    ESP32 gateway that decodes Growatt's low-voltage BMS CAN protocol
    (0x311/0x312/0x313/0x314/0x319, big-endian) and re-emits it as the
    Pylontech LV CAN protocol (0x351/0x355/0x356/0x359/0x35C/0x35E,
    little-endian) that a Solis S6-EH1P8K-L-PLUS understands.
    Contents:
    src/translate.h pure protocol logic, no hardware deps
    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
2026-08-20 Add first-class PlatformIO envs for the budget ESP32 DevKit build
    The DevKit path was already supported in config.h but required manually
    editing both config.h and platformio.ini to switch boards, which is easy
    to get wrong on a project sitting in a battery's control path. BOARD can
    now be overridden at compile time, so translator-devkit/sniffer-devkit
    select the budget hardware with a single -e flag. Wired into CI so the
    budget path is compiled on every push, same as the CAN-X2 path.
    [config.h]
2026-08-20 Add LilyGo T-2Can board support
    Adds BOARD_LILYGO_T2CAN and a translator-t2can PlatformIO env for the
    non-FD T-2Can. Per LilyGo's own pin_config.h and example firmware
    (github.com/Xinyuan-LilyGO/T-2Can), it's one built-in TWAI channel plus
    one external MCP2515 - the same architecture already used for the CAN-X2,
    just different pins - so no porting off TWAI was needed, contrary to the
    prior note in PARTS.md (now corrected). Its MCP2515 exposes RST as a GPIO
    that needs an active-low pulse before SPI.begin(), unlike the other two
    supported boards where it's tied on-board; main.cpp handles this whenever
    MCP_RST_PIN is defined.
    Its TWAI pins (GPIO 7/6) match the CAN-X2's, so the existing sniffer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
    [config.h, main.cpp]
2026-08-20 Update CLAUDE.md build section for the three supported boards
    Was still describing the pre-devkit/t2can world (two boards, no -devkit or
    -t2can envs). Keeping this file in sync as the repo changes matters more
    than usual here - it's the cross-session context brief, and conversation
    history doesn't carry between Claude surfaces.
2026-08-21 Fold in WAKE-pin and 0x311-byte findings from a real-world forum report
    A forum user pairing a GBLI6532 with a non-Growatt inverter independently
    reports: the GBLI does emit 0x311-0x318 (corroborates open question 1),
    WAKE+ at +5V wakes the pack and closes relays (answers open question 4,
    but surfaces a new gap - nothing in this project's firmware currently
    drives that pin, which will likely matter once the GBLI has no real
    Growatt inverter left to do it), and that byte 6 of 0x311 carries
    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
2026-08-21 Add cold-boot capture guidance to the sniffing procedure
    A steady-state capture can't show the 0x301/0x311 power-on handshake or
    when WAKE+ toggles relative to it - both open questions this project
    still needs answered. Documents starting the logger before power-on
    rather than after, why the first ~30s matters most, and a naming
    convention for this capture distinct from a steady-state one. Also fixed
    a stale `sniffer` (should be `sniffer-devkit`) command in
    captures/README.md left over from the board-support work, and synced its
    open-questions list with CLAUDE.md's fuller one.
2026-08-23 Fix 0x319 overriding 0x311's live charge/discharge-enable state
    A real capture spanning idle -> discharge -> charge showed 0x319's enable
    bits are static (0xC0 throughout, including during an actual ~10A
    discharge) while 0x311's correctly track live state. Since translate.h
    trusted 0x319 whenever present, the gateway would have told the Solis
    discharge was never allowed. 0x311 is now authoritative; 0x319 is only
    used as a fallback before the first 0x311 arrives.
    Also pins GROWATT_0x313_VOLT_SCALE to VS_0V01, confirmed by the same
    capture (53.20-53.40V, sane; the 0.1V reading would be ~530V).
    Updates CLAUDE.md's open questions with what the capture resolved, adds
    a regression test (test [9]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
    [config.h]
2026-08-23 Fold in WAKE-pin and power-cycle findings from the GBLI6532 manual
    The battery's own quick installation guide settles the WAKE-pin
    mechanism question: section 5.1 documents "PCS voltage signal activates
    battery" as one of two power-on methods (the other being the unit's
    physical POWER button) - almost certainly what PCS-WAKE+/WAKE- are for.
    Confirms this is a real designed feature, not just a forum workaround,
    though the exact voltage/timing is still unconfirmed.
    Also documents the POWER button itself (hold 2s to turn on/off - the
    correct procedure, found while answering how to power the pack down for
    the next test) and that the battery self-powers-off 25 minutes after
    losing its CAN link,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
2026-08-23 Resolve the WAKE-pin open question: not needed for this project
    Two clean, deliberately-isolated captures (battery-only, and inverter-on-
    then-battery-power-button with the exact moment narrated live) show the
    0x311 enable bits go from mode=0 (disabled) to mode=1 (chg_en=1 dis_en=1)
    within 2-4 seconds of the battery's first frame, once a real inverter is
    already sending 0x301 - exactly what this project's firmware already
    does. No evidence WAKE needs to be driven for Phase 2 hardware.
    Also corrects an earlier wrong theory in the same section (that a
    multi-minute inverter self-test caused the enable flip - it was actually
    an unmentioned manual POWER-button press) rather than just silently
    re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
2026-08-23 Add best-effort sniffer decoding for three undocumented CAN IDs
    0x322/0x323/0x324/0x329/0x330 aren't in Growatt's published spec but
    showed up in real captures. Diagnostic-only, clearly labelled "GUESS:",
    and not used anywhere in translate.h - just makes sniffer output more
    readable while these get confirmed over more captures:
    - 0x324: paged ASCII string, looks like the pack's serial/model number
    (page 0 "GPJ021", page 1 "9522062", page 2 "BB7"/"C07" - the last
    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
2026-08-23 Add real capture files and tidy up the captures folder
    Commits the three capture logs behind today's findings (coldboot,
    battery-only, wake-test) with entries in captures/README.md's table.
    Renamed wake-test.log for naming consistency with the others (missing
    the -sph6000- segment) and updated CLAUDE.md's reference to match.
    A fourth capture (coldboot_batoff.log) was discarded - the battery had
    been left on from a prior test rather than genuinely isolated, its
    useful conclusions were superseded by the two cleaner captures kept
    here, and its name no longer matched what it actually showed.
2026-08-23 Add parametric OpenSCAD enclosure for the Phase 2 translator board
    A 3D-printable box for the LilyGo T-2Can, base + lid, with two RJ45
    coupler cutouts (one per CAN bus - battery and inverter), a USB-C
    cutout, ventilation slots, and 4-corner screw mounting plus wall-mount
    tabs.
    Neither the T-2Can's PCB dimensions nor the RJ45 coupler's exact cutout
    size were confirmable without the physical parts in hand, so every
    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
    [t2can_enclosure.scad]
2026-08-23 Note real-world tolerance of the third-terminator issue, keep the advice
    A real sniffing session (2026-08-23) ran an extended capture - cold
    boot, idle, full charge/discharge cycle, wake tests - with a real
    SN65HVD230 module confirmed (multimeter-verified) to still have its
    120 ohm resistor fitted, running the bus at an out-of-spec 40 ohm the
    whole time. No issues observed on the sniffer's reception or the live
    battery/inverter link. Worth recording as real evidence rather than
    leaving an untested warning standing, but keeping the recommendation to
    remove it - it's still correct practice with no downside, one data
    point on a short low-noise stub isn't a general result, and Phase 2's
    translat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
2026-08-24 Ignore generated enclosure STL exports
    Regenerable from enclosure/t2can_enclosure.scad, same pattern as the
    other build artefacts already ignored here.
2026-08-28 Confirm T-2Can isolation against the real board
    Each CAN channel has its own Mornsun TD501MCAN - an isolated CAN
    transceiver module integrating both power isolation (DC-DC) and signal
    isolation, rated 2500VDC, confirmed via datasheet lookup. Settles the
    isolation caveat that was previously just "LilyGo's marketing is vague
    on mechanism" - it's genuine galvanic isolation per channel, not just
    split ground planes.
2026-08-28 Replace placeholder OpenSCAD enclosure with the real Fusion 360 design
    t2can_enclosure.scad was built from unverified placeholder dimensions
    before the T-2Can board or the RJ45 couplers were in hand. Now that both
    are, the enclosure was properly designed against the real hardware in
    Fusion 360 instead - removing the stale parametric fallback rather than
    keeping it around out of sync with reality.
    Also confirms the Mornsun TD501MCAN's exact pinout from its datasheet
    (RXD/TXD/GND/VCC on the logic side, CANG/CANL/CANH on the isolated bus
    side - CANG being a separate isolated ground, not the same as logic
    GND, means the bus side is 3 conductors, not just the CANH/CANL pair).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
    [BMS_Translator_Case.stl, BMS_Translator_Lid.stl, t2can_enclosure.scad]
2026-08-31 Confirm T-2Can MCP2515 crystal (16MHz) and GPIO 6/7 direction against real hardware
    Traced the real schematic plus the user's own physical continuity check
    (TD501MCAN pin 1 -> MS4553S pin 2) to fully resolve two things:
    - MCP2515 crystal is 16MHz (schematic X1 label "16MHZ+-10ppm", confirmed
    again by the physical crystal's own marking "YC16.0"), not the 8MHz
    this project assumed before. config.h now pinned to MCP_16MHZ.
    - GPIO 6/7 direction is NOT swapped, despite looking that way at first.
    There's an MS4553S 3.3V<->5V level shifter between the ESP32 and each
    TD501MCAN that wasn't in the schematic crops looked at earlier. Tracing
    the full chain through it confirms GPIO 7 = TX, GP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
    [config.h]
2026-08-31 Confirm non-FD T-2Can_V1.0 against the real board
    MCP2515 chip physically visible, matching what this project targets.
    Closes out the T-2Can hardware verification punch list - nothing left
    unconfirmed against the real board.
2026-08-31 Correct the TD501MCAN CANG wiring claim
    CANG doesn't need connecting to the remote device - the datasheet's own
    typical application circuit shows it as NC. Only the optional
    surge-protection circuit uses it, tied to local earth, not the remote
    device's ground. The earlier note here claimed a 3-wire connection was
    needed; standard 2-wire CANH/CANL is correct.
2026-08-31 Fix silent Serial output on translator-t2can (ARDUINO_USB_CDC_ON_BOOT)
    First real hardware bring-up of the translator firmware today hit a
    real gotcha: the chip and USB connection were completely healthy
    (esptool talked to it fine throughout, via the ROM USB-Serial/JTAG
    peripheral), but Serial.print() output never appeared anywhere -
    confirmed independently via both pio device monitor and a raw cat on
    the port. LilyGo's own T-2Can README FAQ documents the same symptom and
    fix: without -D ARDUINO_USB_CDC_ON_BOOT=true, the framework's default
    can leave Serial pointing at a USB personality that isn't actually
    wired up on this board. Added it, reflashed, and confirmed real battery
    frames now flo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
2026-08-31 Add first successful capture from the real translator firmware
    README's Step 3 dry-run (battery bus only, SNIFF_ONLY still on) against
    the real T-2Can hardware for the first time. Clean result: reconnects
    with chg=0 dis=0, reaches chg=1 dis=1 CCL=DCL=25.6A within 4 seconds,
    matching the wake-test capture's enable-timing pattern exactly. No
    faults, SOC/voltage sane, inv0x305=no correctly reflecting the
    unconnected inverter bus.
    Updates README's status banner - the translator firmware itself is now
    confirmed running on real Phase 2 hardware, not just inferred from
    sniffing. What's left unproven is the fully live path with SNIFF_ONLY
    off and a real Solis attached.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
2026-08-31 Flesh out Step 4 with confirmed Solis menu paths and recommended limits
    Pulled the exact HMI navigation and Battery Setting screen fields
    directly from the real Solis manual rather than the previous vague
    "set conservatively" note. Adds specific starting recommendations
    (20-30A charge/discharge, 95% max charge SOC) with reasoning tied to
    this being the first live run of the whole chain, and flags that the
    gateway's 105A ceiling in config.h is a safety clamp, not a confirmed
    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
2026-08-31 Scale the charge/discharge ceiling with the real pack count
    Confirmed against the real GBLI6532 datasheet: 5kW / 104.2A max per
    pack. The fixed 105.0A ceiling this project used before wasn't far off
    by coincidence, but for a 2-pack system (like the one this project has
    been developed against all along) it was silently halving the real
    combined capability - the BMS's own reported 208.4A CCL/DCL, which
    showed up throughout the captures, was always the correct real limit,
    not a placeholder as briefly speculated.
    Ceiling now computed as CCL_MAX_PER_PACK_dA * pack_count at build time,
    using the live pack count from 0x312 rather than a fixed number - a
    single-pack system still correctly gets clam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
    [config.h]
2026-08-31 Update Step 4's ceiling note now that it's a confirmed rating
    Written before the real datasheet check - said the gateway's clamp
    wasn't a confirmed number for this pack. It is now.
2026-08-31 Document the first fully live run - real GBLI6532, real T-2Can, real Solis
    The actual goal of this whole project, working: SNIFF_ONLY off, DC
    power connected, a genuine charge cycle and a genuine discharge cycle
    both with correct current sign and correct SOC, and the Solis's own
    display confirming CCL/DCL=208.4A exactly matching the datasheet-derived
    2-pack ceiling from earlier today.
    Two captures:
    - solis-live-nodc: CAN-live but DC deliberately disconnected first, to
    validate the entire data path with zero possibility of real current
    flow. Solis correctly showed "No Battery" as its overall status while
    still displaying valid BMS-mirrored data - sensibly distinguishing
    "valid comms"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
2026-08-31 Investigate and characterize the 594s enable-to-disable timer
    Real, reproducible finding from live commissioning: the GBLI6532 latches
    chg_en=0 dis_en=0 exactly 594s after every enable when driven by this
    gateway, with no self-recovery and no visibility via prot/warn bytes.
    Confirmed three times independently, including in the cleanest possible
    battery+gateway-only topology (no Solis, no SPH6000).
    Reconnected the real SPH6000 directly to the battery to get ground truth:
    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
2026-09-03 Rule out WAKE, extended IDs, and inverter rate; find a real 0x323 lead
    Three more theories chased down and eliminated for the 594s mystery:
    built an isolated WAKE-pin monitor and confirmed zero pulses across a
    full disable and re-enable cycle; checked another project's Growatt
    decoder that uses extended CAN IDs and confirmed the real hardware
    never uses them; confirmed the real inverter's own keepalive rate does
    spike, but only at connection, not periodically during steady operation.
    A full byte-by-byte diff across every ID (not just the ones already
    decoded) around two independent disable/re-enable transitions turned up
    the first real lead all project: 0x323 byte 4 flips 0x00->0x04 tightly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
    [config.h, main.cpp, sniffer.cpp]
2026-09-03 Fix the wrong 0x301 keepalive payload - root cause of the 594s disable
    sendGrowattKeepalive() had been sending the Growatt protocol doc's
    example placeholder (11 22 33 44 55 66 77 88) instead of the real
    captured payload (0B 16 21 2C 37 42 4D 58) since the project's first
    commit. Every prior "gateway can't sustain/revive the battery" finding
    was made while this bug was live. Corrected the payload and confirmed
    via a 46+ minute live test with zero disables, ~5x past the old wall.
    Also rules out WAKE (three independent methods), verifies
    twai_transmit() reliability with VERBOSE_KEEPALIVE_TX, and reframes
    the 594s timer as the battery's own default behavior rather than
    anything this gateway tr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
    [main.cpp, sniffer.cpp]
2026-09-03 Go live: flip SNIFF_ONLY to false
    Now that the wrong 0x301 payload is fixed and confirmed stable for
    50+ minutes with zero disables, switching the translator from
    listen-only to actually driving the Solis.
    [config.h]
2026-09-03 Note that battery temperature has no field in the Solis PYLON_LV UI
    Verified our 0x356 encoding against the real Pylon CANBUS Protocol
    V1.2 spec directly - byte 4-5, 0.1C, signed 16-bit little-endian is
    exactly correct, and there's no separate min/max-temp frame in the
    spec Solis could be expecting instead. Looks like a Solis UI
    limitation for this battery profile, not a translation bug.
2026-09-05 Clear out stale hardware caveats now proven live
    Two real inaccuracies fixed, not just rewording:
    - README/PARTS.md both still said T-2Can pin/wiring details "still need
    confirming," contradicting PARTS.md's own detailed section which had
    already confirmed everything as of 2026-08-31. Days of live operation
    since then is stronger confirmation still.
    - README's "catches people out" WAKE-pin note was actively misleading -
    it told readers WAKE might be needed and to treat it as "the first
    suspect" for a silent battery bus, which this project has since ruled
    out three independent ways (validated optocoupler monitor, multimeter,
    and a CAN-only cable that both sustained and revived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
2026-09-08 Mark project complete: live system runs upstream Battery-Emulator
    The Growatt LV driver and PYLON-LV-CAN sign-bug fix both merged
    upstream, and the live T-2Can now runs dalathegreat/Battery-Emulator's
    main branch directly instead of this repo's own translator firmware.
    Updates the status note and closes out the "Future direction" section
    accordingly.
